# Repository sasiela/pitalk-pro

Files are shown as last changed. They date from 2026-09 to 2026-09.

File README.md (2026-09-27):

# PiTALK PRO

**[Download the complete latest STL set](releases/PITalk-Final-STL-V39-V42.zip)** · [STL files](stl/PITalk-Final-STL-V39-V42/)

**A Raspberry Pi radio terminal project with a custom, 3D-printable handheld enclosure.**

[Polski](README.pl.md) · [Printable parts](#printable-parts) · [Hardware](#hardware) · [Assembly](#assembly) · [Watch the demo](Video/PiTalk-Pro-z-lektorem.mp4)
[Changelog](CHANGELOG.md) · [Profiles / Profile](docs/build/PROFILES.md)

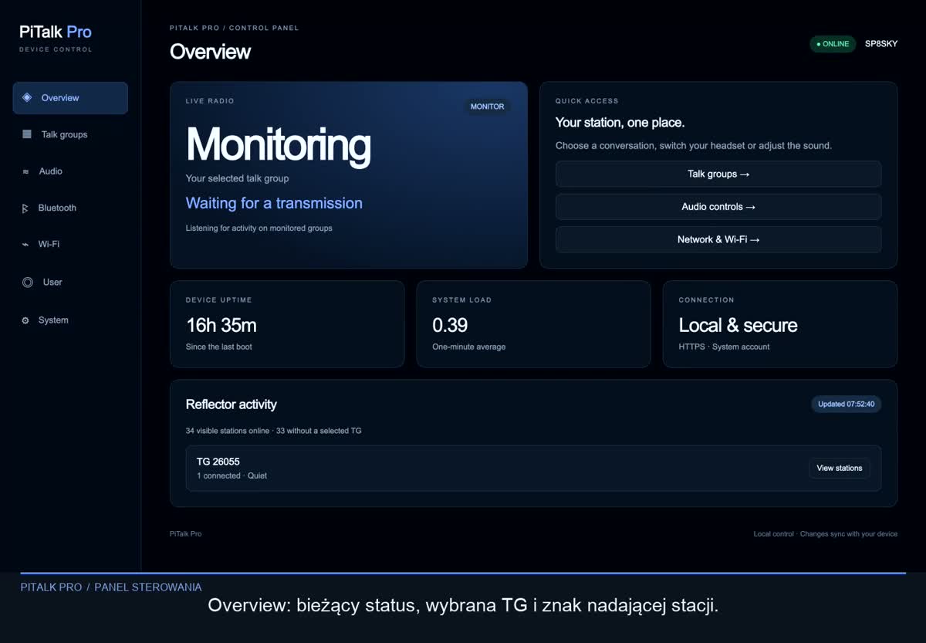
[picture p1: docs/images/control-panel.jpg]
PiTALK PRO control panel — open the demonstration video


*Control panel preview from the project demonstration. The video includes Polish narration.*

## Build your own PiTalk Pro

This repository is the shared home for the enclosure, software, configuration examples and build knowledge. Start with the [documentation hub (Polish)](docs/README.md), [build guide](docs/build/README.md), [parts list](docs/build/HARDWARE.md) and [project readiness](docs/project/READINESS.md).

**Current status: working prototype, reproduction in progress.** A complete clean-install procedure and physical alpha-image boot test are still pending. The repository does not yet provide a validated firmware download. See [contributing](CONTRIBUTING.md) to help complete the build documentation.

## About the project

PiTALK PRO brings a Raspberry Pi 3 Model B, an Adafruit PiTFT 2.2″ display and a Sabrent USB sound card into a custom enclosure inspired by classic handheld radios. Four physical buttons sit beside the display. The enclosure includes a separate front panel, ventilation, decorative knobs and a removable decorative antenna.

This repository contains **printable STL models, demonstration materials and a software source snapshot**. Start software development with [the project handoff](docs/handoff/START-HERE.md) and [software notes](software/README.md). The software snapshot and experimental image tooling are not yet a validated public firmware release.

The mechanical design was refined through repeated physical print-and-fit checks. The latest CAD pair is **V39 body + V42 front**, with **V11 button caps**; the previous V32/V38 set remains available. Fit still depends on the exact hardware and printer tolerances.

## Printable parts

Download the repository with **Code → Download ZIP**, or open an individual file below. Dimensions are in **millimetres**.

### Latest revision: EC11 body V39 + front V42

The latest CAD pair is **V39 body + V42 front**, extended by 8 mm at the top for one EC11 encoder and one decorative antenna. V42 has **two rows of three ventilation slots above the display**. Use these two revisions together.

| Part | Print | Editable CAD |
| --- | --- | --- |
| Body V39 | [STL](stl/ec11-v39-v42/01_Body_V39.stl) | [STEP](step/ec11-v39-v42/01_Body_V39.step) |
| Front V42 | [STL](stl/ec11-v39-v42/02_Front_Panel_V42.stl) | [STEP](step/ec11-v39-v42/02_Front_Panel_V42.step) |

Reuse four V11 caps and the decorative antenna/base from the list below. The old decorative knobs are not the encoder knob. The encoder knob and electrical integration are still pending. The 20 mm upper test print fitted; full assembly of this revision remains to be checked. See [revision dimensions and assembly differences](docs/build/MECHANICAL-EC11.md).

### Previous decorative-knob set: V32 + V38

| Part | STL file | Print quantity |
| --- | --- | ---: |
| Body with ventilation and reinforced nut mounts | [Body V32](stl/01_Body_V32.stl) | 1 |
| Flat front panel with display window and grille | [Front V38](stl/02_Flat_Front_Panel_V38.stl) | 1 |
| Rounded button cap | [Button cap V11](stl/03_Button_Cap_V11_Print_4.stl) | **4** |
| First decorative knob | [Control knob 1](stl/04_Control_Knob_1.stl) | 1 |
| Second decorative knob | [Control knob 2](stl/05_Control_Knob_2.stl) | 1 |
| Decorative antenna base | [Antenna base](stl/06_Antenna_Base.stl) | 1 |
| Decorative 70 mm antenna | [Antenna](stl/07_Decorative_Antenna_70mm.stl) | 1 |

**Seven STL files, ten printed parts.** The button-cap file contains a single cap.

### Current design details

- Flat front surface between the recessed grille rows, replacing the earlier raised curved ribs.
- Forty bottom ventilation slots in eight rows of five; each slot is 6.6 × 2.6 mm with R1 corners.
- Reinforced lower corner mounts joined to the enclosure walls.
- Side-entry pockets for M3 nuts measuring **5 mm across flats × 2 mm thick**. Pocket clearance is **5.5 × 2.6 mm**.
- Lower front fixings use **countersunk M3 × 12 mm screws**.
- V11 button caps are 3.5 mm tall overall, with an R0.6 top edge.

## Hardware

| Component | Design reference / notes |
| --- | --- |
| Raspberry Pi | **3 Model B**; compatibility with other boards has not been established |
| Display | **Adafruit PiTFT 2.2″ 240 × 320 HAT**, with four onboard buttons |
| USB audio | Sabrent adapter used in the prototype; measured housing approximately **34 × 23 × 10 mm** |
| Side push button | PBS-110-style momentary button matching the prototype; check dimensions before ordering |
| Lower front fasteners | **2 × countersunk M3 × 12 mm** and **2 × M3 nuts**, measured 5 mm across flats and 2 mm thick |
| Display/front fasteners | Four countersunk M3×12 screws and four spacers; spacer length still needs documenting |
| Power | External power supply appropriate for the Raspberry Pi; no internal battery compartment |

Measure replacement components before printing. A shared product name does not guarantee the same casing or shaft dimensions. Keep the existing display spacers and check the front screw length against the assembled stack.

The supplied knobs and antenna are **decorative**. The V39/V42 revision adds an EC11 mounting provision; its knob, wiring and software integration are not yet validated. External-radio PTT electronics are also outside this mechanical release.

## Printing

The project was developed using a **Creality K1**. PLA and Creality CR-PETG were used during development; this repository does not include a validated slicer profile or G-code.

- Inspect every model in your slicer and choose settings for your printer and material.
- Print the body with its exterior bottom on the build plate.
- The V38 front STL is positioned with its flat front toward the build plate. Check the first-layer preview and bed texture before printing.
- Review supports for overhangs, particularly the nut-pocket roofs, button-cap flanges and decorative parts.
- Print one button cap first and check movement in the front panel before printing the remaining three.
- A lower layer height can improve finish, but cannot compensate for poor orientation, support contact or inaccurate fit.

## Assembly

Follow the [full assembly guide](docs/build/ASSEMBLY.en.md), with the [illustrated Polish version](docs/build/ASSEMBLY.md). Assemble the front first:

1. Place the four button caps into the front slots.
2. Insert four M3×12 screws, fit the LCD and tighten gently.
3. Screw on the four spacers; set the completed front aside.
4. Solder two 10 cm wires to PTT and insulate the joints with heat-shrink tubing.
5. Mount PTT in the rear enclosure and secure its body with hot glue.
6. Bend physical Pi header pins 37 and 39 inward, solder the PTT wires and insulate the joints as described in the full guide.
7. Fit optional dongles into the lower USB sockets before placing the Pi in the case.
8. Insert the Raspberry Pi, then the two M3 nuts and the microSD card.
9. Install the USB sound adapter.
10. Fit the completed front and tighten the two lower M3×12 screws.

## Repository layout

```text
stl/                  Printable enclosure and accessory parts
Video/                Project demonstration with Polish narration
docs/images/          README preview image
README.md             English project page
README.pl.md          Polish project page
```

## Feedback

For fit problems, include the part/version, printer, material, layer height and a photo or measured discrepancy in a [GitHub issue](https://github.com/sasiela/pitalk-pro/issues).

## On-device updates / Aktualizacje z urządzenia

[System Update: instrukcja i zakres aktualizacji](docs/build/UPDATES.md). Pierwsza wersja obejmuje ekran i enkoder; nie aktualizuje całego systemu ani panelu WWW.

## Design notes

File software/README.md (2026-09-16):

# PiTalk Pro software snapshot

Start with [the project handoff](../docs/handoff/START-HERE.md) and [AGENTS.md](../AGENTS.md).

`rootfs/` mirrors installation paths for the current Python application, web assets, systemd units and supporting scripts. It is an exported source snapshot, not a complete Raspberry Pi filesystem or automatic installer. Owner identifiers were scrubbed; the web LAN filter contains example addresses and requires adjustment before deployment. `manifest.json` records source/export hashes and original permissions.

`examples/` contains credential-free configuration examples. Never overwrite an active configuration with these templates. `image-tools/` contains experimental alpha image tooling and its limitations. Read its README before use.

Run `python3 software/check-source.py` from the repository root for static checks. These do not test actual hardware. The repository does not establish a new license for bundled upstream service files; preserve their existing notices and review licensing before distribution.

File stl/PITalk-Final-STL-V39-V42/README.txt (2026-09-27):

PiTALK PRO — latest STL set — 2026-09-27
Units: millimetres.

01_Body_V39.stl — print 1
02_Front_Panel_V42.stl — print 1 (two upper ventilation rows)
03_Button_Cap_V11_Print_4.stl — print 4 (original 3.5 mm height)
04_Antenna_Base.stl — print 1
05_Decorative_Antenna_70mm.stl — print 1

5 STL files, 8 printed pieces.
Body V39 and front V42 are the matching extended EC11 revision.
Old decorative knobs are not included: this revision uses one real EC11
encoder. A matching encoder knob has not yet been designed.
The upper test print fitted; full assembly of V39/V42 remains to be verified.
Previous versions have been preserved separately.

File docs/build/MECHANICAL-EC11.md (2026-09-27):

# EC11 mechanical revision — V39 body / V42 front

Updated: 2026-09-26. Units: mm. This is the latest CAD revision, not a fully validated assembled release.

## Files and compatible parts

- [Body V39 STL](../../stl/ec11-v39-v42/01_Body_V39.stl) / [STEP](../../step/ec11-v39-v42/01_Body_V39.step).
- [Front V42 STL](../../stl/ec11-v39-v42/02_Front_Panel_V42.stl) / [STEP](../../step/ec11-v39-v42/02_Front_Panel_V42.step).
- Reuse [V11 caps](../../stl/03_Button_Cap_V11_Print_4.stl), four prints, and the existing [antenna base](../../stl/06_Antenna_Base.stl) and [70 mm decorative antenna](../../stl/07_Decorative_Antenna_70mm.stl).
- Previous decorative knobs are legacy parts. A matching encoder knob is not included.

## Geometry

The upper body and front extend by 8 mm. PCB supports, display position and existing screw axes stay in place. The upper walls are continuous; the antenna-side bulge reaches the upper edge. The old microSD opening is closed. There is one EC11 position and one antenna position; the middle decorative-knob position is removed.

Encoder reference supplied by the builder: body 12 × 12 × 5, depth including terminals 10, shaft plus threaded section 20. The mounting hole is Ø7.2; verify the actual threaded bush, washer and nut before assembly. The nominal 10 mm envelope reaches 1.7 mm into the PCB footprint, so clearance to real components and wiring must be checked in the complete assembly. Shaft flat, usable shaft length and push travel still need confirmation for the knob.

| Feature | Dimensions |
| --- | --- |
| Rear holes through four existing PCB supports | Ø3.4 |
| Rear countersinks | Ø6.4 at surface, depth 2.2 |
| Rear screw-axis rectangle | 58 × 49 |
| Bottom vents | 40 slots, 8 rows × 5; 6.6 × 2.6, R1 |
| Bottom vent placement | Centered between the four rear screw axes |
| Above-screen vents | 2 rows × 3; 6.6 × 2.6, R1 |
| Above-screen row pitch / material gap | 6 / 3.4 |

## Assembly differences / różnice montażowe

The [illustrated assembly guide](ASSEMBLY.en.md) describes the earlier prototype. For this revision:

1. Trial-fit the encoder and its retaining nut before installing the electronics. Check terminal insulation and clearance to both Pi and display HAT.
2. Insert the microSD before closing the enclosure; there is no external card slot.
3. Rear M3 screws must mate with suitable threaded spacers. Select screw length from the actual assembled stack; the existing M3×12 front screws do not establish the required rear length.
4. Reuse the established front fasteners and V11 caps. Check free button travel after closing.
5. Encoder wiring and software support are not provided by this mechanical change.

Po polsku: montuj V39 z V42. Przymierz enkoder przed elektroniką, sprawdź izolację i kolizje pinów, a kartę microSD włóż przed zamknięciem. Długość tylnych śrub M3 dobierz do rzeczywistych gwintowanych dystansów. Stare pokrętła są ozdobne; nowa gałka i podłączenie EC11 wymagają dopracowania.

## Verification

- Builder confirmed that the 20 mm upper-body test print fitted.
- CAD checks: valid single solids, STEP reimport successful, 40 body vents and six upper-front vents open, no body/front intersection in the checked assembly.
- Full V39/V42 physical assembly, rear fasteners, encoder clearance with soldered wires, and encoder operation remain unverified.
- Check orientation and supports in the slicer; these files do not include a validated print profile.

## Zestaw do pobrania — 2026-09-27

[Kompletny ZIP STL V39/V42](../../releases/PITalk-Final-STL-V39-V42.zip): 5 modeli, 8 drukowanych części. Sprawdzono zgodność kopii i integralność archiwum. Zakres potwierdzenia montażu pozostaje bez zmian; gałka EC11 nie jest jeszcze gotowa.

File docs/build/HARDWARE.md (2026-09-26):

# Sprzęt i połączenia

## Zestaw odniesienia

Lista opisuje użyty prototyp, a nie gwarantowane zamienniki. Wersja maszynowa: [parts.csv](parts.csv).

| Element | Ilość | Znane dane / do uzupełnienia |
| --- | ---: | --- |
| Raspberry Pi 3 Model B Rev 1.2 | 1 | Model potwierdzony odczytem systemu |
| Adafruit PiTFT 2.2″ 240×320 HAT | 1 | Cztery przyciski; overlay `pitft22` |
| Karta dźwiękowa USB Sabrent | 1 | Obudowa prototypu około 34×23×10 mm; dokładny numer produktu i identyfikator USB do zapisania |
| Boczny przycisk chwilowy | 1 | Typ PBS-110 zgodny wymiarami z prototypem; przed zakupem sprawdzić konkretny wariant |
| microSD | 1 | Obraz alpha wymaga minimum 8 GB; karta testowa osobna od działającej instalacji |
| Zewnętrzne zasilanie i kabel | 1 zestaw | Dokładny model zasilacza i sprawdzenie pracy pod obciążeniem do udokumentowania |
| Mikrofon i odsłuch USB lub zestaw Bluetooth | 1 tor | Brak kompletnej listy sprawdzonych modeli i okablowania audio |
| Śruby stożkowe M3×12 | 2 | Dolne mocowanie frontu |
| Nakrętki M3 | 2 | W prototypie 5 mm między płaskimi bokami, grubość 2 mm |
| Śruby M3×12 do LCD / dystanse | 4 śruby + 4 dystanse | Śruby potwierdzone przez autora; długość dystansów do zwymiarowania |
| Przewody PTT i izolacja | 2 × około 10 cm | Koszulki termokurczliwe na każdym lucie; klej na gorąco do zamocowania przycisku |
| Części drukowane — poprzedni zestaw | 10 | Korpus V32, front V38, 4 nakładki V11, 2 pokrętła, podstawa i antena |
| Najnowsza mechanika EC11 | Zobacz opis | [Korpus V39 + front V42](MECHANICAL-EC11.md), 4 nakładki V11, podstawa i antena; gałka enkodera do opracowania |

## Połączenia

Poniższe numery to **BCM, nie kolejne numery fizycznych pinów złącza**. Tabela opisuje konfigurację oprogramowania. Nie zastępuje sprawdzonego schematu montażowego.

| BCM | Rola |
| --- | --- |
| 17 | Przycisk BACK na PiTFT |
| 22 | Przycisk UP na PiTFT |
| 23 | Przycisk DOWN na PiTFT |
| 27 | Przycisk ENTER na PiTFT |
| 26 | Wejście PTT, pull-up, aktywne LOW; programowy debounce 30 ms |
| 24 | Programowy sygnał squelch: HIGH oznacza idle, LOW aktywuje wejście SvxLink |

Przycisk PTT łączy **fizyczny pin 37 (GPIO26)** z **fizycznym pinem 39 (GND)** po wciśnięciu. Autor podał tę kolejność montażu, a [zdjęcie połączeń](../../photos/IMG_3615.jpeg) pokazuje luty zabezpieczone koszulkami. Pełny opis i źródło numeracji: [instrukcja montażu](ASSEMBLY.md#numeracja-i-kontrola-ptt). Powyższa tabela nadal używa numeracji BCM. Nie podłączaj wyjścia zewnętrznego radia do wejścia przycisku.

GPIO24 jest sterowane przez system jako `gpio536` w prototypie. Ta liczba zależy od mapowania GPIO w jądrze. Nie jest numerem fizycznego pinu. Nie przenoś jej bez sprawdzenia na inny model/system.

## Mechanika i dokumentacja zdjęciowa

Obowiązują [wersje STL i instrukcja montażu](../../README.pl.md). Najpierw wydrukuj jedną nakładkę i wykonaj przymiarkę. Pokrętła i antena są ozdobne; nie ma zintegrowanego akumulatora ani potwierdzonej obsługi enkoderów.

[Instrukcja montażu ze zdjęciami](ASSEMBLY.md) prowadzi od frontu, przez PTT, do zamknięcia obudowy. [Indeks zdjęć](../../photos/README.md) opisuje wszystkie 24 pliki. Ostatnie etapy zamknięcia obudowy są opisane według autora, ale nie mają jeszcze osobnych zdjęć. Wymiary dystansów i kompletny rysunek montażowy pozostają do uzupełnienia.

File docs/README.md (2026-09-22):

# PiTalk Pro — dokumentacja projektu

Celem repozytorium jest umożliwienie innej osobie zbudowania, skonfigurowania i rozwijania własnego PiTalk Pro. Wspólnie przechowujemy obudowę, kod, konfiguracje przykładowe, instrukcje i wyniki testów. Wiedza potrzebna do budowy nie powinna wymagać dostępu do prywatnej rozmowy ani komputera autora.

**Stan: działający prototyp i dokumentowana wersja rozwojowa.** Instrukcja odtworzenia na czystej karcie nie została jeszcze potwierdzona. Nie ma opublikowanego, przetestowanego wydania obrazu ani kompletnego instalatora. Braki są widoczne w [statusie odtwarzalności](project/READINESS.md).

## Chcę zbudować urządzenie

1. [Przewodnik budowy](build/README.md) — kolejność prac i punkty kontrolne.
2. [Sprzęt i połączenia](build/HARDWARE.md) — części, GPIO i brakujące dane.
3. [Montaż krok po kroku ze zdjęciami](build/ASSEMBLY.md) oraz [pliki STL](../stl/).
4. [Instalacja i pierwsza konfiguracja](build/SOFTWARE.md) — dostępne ścieżki i ich ograniczenia.
5. [Test własnego egzemplarza](testing/ACCEPTANCE.md) — co sprawdzić przed uznaniem budowy za zakończoną.

## Chcę używać lub rozwijać projekt

- [Architektura](handoff/ARCHITECTURE.md) i [obsługa/diagnostyka](handoff/OPERATIONS.md).
- [Znane problemy](handoff/KNOWN-ISSUES.md) oraz [historia decyzji interfejsu](handoff/HISTORY-AND-UX.md).
- [Kod](../software/README.md), [zasady współpracy](../CONTRIBUTING.md), [instrukcje dla asystentów](../AGENTS.md).
- [Obraz i backupy](handoff/IMAGE-AND-BACKUPS.md), [status przygotowania wydania](project/READINESS.md).

Materiały w `docs/handoff/` zachowują kontekst rozwoju. Niniejszy katalog jest punktem wejścia dla wszystkich budujących, niezależnie od używanego edytora lub asystenta.

## Profile połączenia

[Konfiguracja i obsługa profili SQLink / Fala](build/PROFILES.md) — wspólne dla ekranu i panelu WWW.

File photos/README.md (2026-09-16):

# Zdjęcia montażu

[Instrukcja krok po kroku](../docs/build/ASSEMBLY.md). Poniżej wszystkie 24 zdjęcia w kolejności nazw plików. Kolejność montażu określa instrukcja autora; IMG_3612 wraca do detalu wcześniej przygotowanego frontu. Oryginałów nie zmieniono.

| Zdjęcie | Co pokazuje |
| --- | --- |
| [IMG_3595](IMG_3595.jpeg) | Front od środka: nakładki w slotach i cztery śruby. |
| [IMG_3596](IMG_3596.jpeg) | Cztery dystanse przed montażem. |
| [IMG_3597](IMG_3597.jpeg) | Płytka PiTFT nałożona na śruby frontu. |
| [IMG_3598](IMG_3598.jpeg) | Widok frontu z zamontowanym LCD. |
| [IMG_3599](IMG_3599.jpeg) | Front z LCD — drugi widok. |
| [IMG_3600](IMG_3600.jpeg) | Front z LCD — widok pod kątem. |
| [IMG_3601](IMG_3601.jpeg) | Cztery dystanse przykręcone z tyłu LCD. |
| [IMG_3602](IMG_3602.jpeg) | Pusta tylna część obudowy. |
| [IMG_3603](IMG_3603.jpeg) | Przycisk PTT przed przygotowaniem przewodów. |
| [IMG_3604](IMG_3604.jpeg) | Przewody przylutowane do PTT, luty w koszulkach. |
| [IMG_3605](IMG_3605.jpeg) | Wnętrze obudowy i gniazdo przycisku. |
| [IMG_3606](IMG_3606.jpeg) | Wnętrze obudowy — inne ujęcie. |
| [IMG_3607](IMG_3607.jpeg) | Podpory płytki i przestrzeń montażowa. |
| [IMG_3608](IMG_3608.jpeg) | PTT osadzony w obudowie, przewody prowadzą do wnętrza. |
| [IMG_3610](IMG_3610.jpeg) | Ułożenie przewodów od zamontowanego PTT. |
| [IMG_3611](IMG_3611.jpeg) | Korpus PTT zabezpieczony klejem na gorąco. |
| [IMG_3612](IMG_3612.jpeg) | Zbliżenie tylnej strony LCD z dystansami. |
| [IMG_3613](IMG_3613.jpeg) | Raspberry Pi przed przylutowaniem przewodów; końcówka złącza przygotowana. |
| [IMG_3614](IMG_3614.jpeg) | Obudowa połączona przewodami PTT z płytką leżącą obok. |
| [IMG_3615](IMG_3615.jpeg) | Zbliżenie połączeń PTT i koszulek przy pinach 37 i 39. |
| [IMG_3616](IMG_3616.jpeg) | Raspberry Pi umieszczone w obudowie. |
| [IMG_3617](IMG_3617.jpeg) | Raspberry Pi w obudowie — ułożenie przewodów. |
| [IMG_3618](IMG_3618.jpeg) | Widok otworu dostępu do gniazda microSD. |
| [IMG_3619](IMG_3619.jpeg) | Karta dźwiękowa USB Sabrent przed instalacją. |

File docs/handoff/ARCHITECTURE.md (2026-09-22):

# Architektura i sprzęt

## Platforma odniesienia

Raspberry Pi 3 Model B Rev 1.2, Debian GNU/Linux 13 (trixie), aarch64. W czasie diagnozy system podawał Debian 13.6 i kernel 6.18.39+rpt-rpi-v8. Wyświetlacz Adafruit PiTFT 2.2 cala, 240×320, nakładka `pitft22`. Ekran jest rysowany przez Pillow i zapisywany do `/dev/fb0` jako RGB565. Czcionki DejaVu są zależnością systemową. To nie aplikacja desktopowa ani strona na samym ekranie PiTFT.

| GPIO BCM | Funkcja |
| --- | --- |
| 17 | BACK |
| 22 | UP |
| 23 | DOWN |
| 27 | ENTER |
| 26 | Przytrzymywany przycisk PTT, wejście z pull-up, aktywne zero |
| 24 | Programowy sygnał otwarcia squelcha; w tym jądrze sysfs `gpio536` |

Nie traktuj liczby 536 jako uniwersalnego numeru GPIO. Wynika z mapowania konkretnego systemu. Przycisk PTT był testowany z eliminacją drgań 30 ms; bez niej rejestrował serię krótkich zboczy.

## Warstwy

- `/usr/local/bin/sqlink-screen.py`: główny ekran i menu, przyciski, renderowanie, TG i wskaźniki.
- `/usr/lib/sqlink/`: kontroler, API SQLink, stan reflektora, GPIO, audio, motywy i edytory poszczególnych menu.
- `/usr/local/bin/sqlink-ptt-button.py`: oddzielny proces przycisku, debounce 30 ms, uzbrojenie dopiero po puszczeniu przycisku, watchdog i zwolnienie PTT przy wyjściu.
- `/usr/local/sbin/sqlink-gpio-setup.sh`: eksport GPIO24/sysfs, atomowe ustawienie stanu idle HIGH, prawa do sterowania dla aplikacji.
- `svxlink.service`: silnik głosu i połączenie z reflektorem. Konfiguracja zawiera SimplexLogic i ReflectorLogic połączone przez ReflectorLink.
- Uprzywilejowane helpery Wi-Fi oraz Bluetooth: wykonują ograniczone operacje systemowe za pośrednictwem lokalnych socketów Unix.
- `/opt/sqlink-web/server.py` i `static/`: lokalny panel WWW. Korzysta z tych samych modułów i helperów co ekran.

## PTT i audio

GPIO26 → proces PTT → `sqlink.gpio` → GPIO24 w stanie LOW → `Rx1` z `SQL_DET=GPIO` i `GPIO_SQL_PIN=!gpio536` → audio mikrofonu do SvxLink/reflektora. W konfiguracji prototypu `Tx1` ma `PTT_TYPE=NONE`. Jest to sterowanie lokalnym wejściem głosowym do sieci; nie oznacza gotowego interfejsu PTT zewnętrznego radiotelefonu.

SvxLink używa `AUDIO_DEV=alsa:pipewire`. PipeWire, warstwa zgodna z PulseAudio i WirePlumber pracują w sesji konta `sqlink`. UID 1002 jest wpisany w kilka usług i ścieżek `/run/user/1002`. Wybór USB/Bluetooth oraz głośność opierają się na `pactl` i helperze Bluetooth. Profile Bluetooth mają znaczenie dla wejścia mikrofonowego i jakości dźwięku; nie zakładaj, że każdy profil zapewnia równocześnie to samo wejście i wyjście.

## Stan TG i nadawcy

`/usr/share/svxlink/events.d/local/RadioStatus.tcl` opakowuje zdarzenia ReflectorLogic (`tg_selected`, `talker_start`, `talker_stop`). Zapisuje atomowo `/dev/shm/sqlink-radio-state`: PID, TG, flaga odbioru i callsign. Czytelnicy porównują PID z `/run/svxlink.pid`, aby odrzucić stan sprzed restartu.

- MONITOR: brak aktywnego RX/TX przy gotowości do nasłuchu.
- RX: aktualnie odbierana transmisja; wyświetlany jest callsign i pasek audio.
- TX: aktywny lokalny PTT. Nie jest to dowód, że mikrofon faktycznie dostarcza sygnał lub że transmisja dotarła do serwera.
- ONLINE/OFFLINE: rzeczywisty lokalny stan połączenia SvxLink. API statusu serwera daje informacje dodatkowe.

`radio_status.py` pobiera próbki przez `parec` w osobnym wątku; szybsze rysowanie miernika nie powinno wymuszać kosztownych zapytań sieciowych przy każdej klatce.

## Panel WWW

HTTPS na porcie 8443, Python HTTP server i statyczny HTML/CSS/JS. Ekrany: Overview, Talk groups, Audio, Bluetooth, Wi-Fi, User, System. Logowanie jako systemowy użytkownik `sqlink` przez PAM (`/etc/pam.d/sqlink-web`, helper `sqlink_web_auth.py`). To nie hasło do reflektora. Sesje są trzymane w pamięci, dlatego restart panelu może wymagać ponownego logowania. Operacje używają tokenu CSRF; panel ma filtr klienta LAN i nagłówka Host.

Talk groups pokazuje aktywność, wybraną TG i listy stacji. „Connected” oznacza aktualnie wybraną TG według danych serwera. „Monitoring” oznacza skonfigurowaną listę monitorowania, nie gwarancję aktywnego odbioru w tej chwili. Kliknięcie callsign otwiera szczegóły stacji z dostępnych danych API, nie zdalną konfigurację administracyjną tej stacji.

Odsłuch: `/api/listen` → `listen_audio.py` → monitor bieżącego wyjścia PulseAudio (`<sink>.monitor`) → PCM s16le/16 kHz/mono → AudioWorklet przeglądarki. Maksymalnie cztery strumienie. Poza RX wysyłana jest cisza. Strumień nie zapisuje nagrania i nie zabiera dźwięku urządzeniu. Głośność przeglądarki jest osobna. Zmiana domyślnego wyjścia jest wykrywana podczas odsłuchu. Zamknięcie Overview, Stop lub wylogowanie zatrzymuje odsłuch.

Pułapka: `ProtectHome=yes` w usłudze ukrywa `/run/user`. Działający prototyp używa bind mount socketu PulseAudio do `/run/sqlink-web-audio` i zmiennej `PULSE_SERVER`. Obraz alpha ma inny wariant: bind całego runtime użytkownika z zależnością od `user@1002.service`. Nie mieszaj tych wariantów bez sprawdzenia startu usług.

## Testy audio WWW

`audio_test.py` obsługuje jedno ograniczone czasowo zadanie należące do sesji. Paplay odtwarza wygenerowany ton, parec odczytuje domyślny mikrofon i oblicza poziom bez zapisu nagrania. GET/POST `/api/audio-test`; frontend odpytuje stan co 250 ms. Test nie steruje GPIO; odczytuje stan radia i przerywa przy RX/PTT. [Instrukcja i sprawdzenia](../build/AUDIO-TESTS.md).

## Profile reflektorów (22 września 2026)

`sqlink_profiles.py` zastępuje bezpośrednią edycję konta w User. Root przechowuje bazę prywatną i publikuje metadane aktywnego profilu do `profile_state.py`. UI PiTFT i `/api/profiles` korzystają ze wspólnego helpera. API nazw i stacji jest ograniczone do dostawcy danego profilu; None nie odpytuje SQLink. Usługa `sqlink-profiles.service` przygotowuje konfigurację domyślnego profilu na rozruch. [Pełny opis](../build/PROFILES.md).

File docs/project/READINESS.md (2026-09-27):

# Kompletność i droga do wydania

Aktualizacja: 16 września 2026. Cel: repozytorium ma wystarczać do zbudowania własnego urządzenia, bez dostępu do prywatnych danych autora.

| Obszar | Stan | Następny konkretny rezultat |
| --- | --- | --- |
| Modele i mechanika | STL, kolejność autora i instrukcja zdjęciowa dostępne | Zdjęcia końcowego zamknięcia i wymiary dystansów |
| Lista części | Referencje dostępne, niektóre identyfikatory niepełne | Numery produktów/USB, zasilanie i komplet audio |
| Schemat | BCM oraz PTT na fizycznych 37/39 opisane i pokazane | Kompletny rysunek montażowy i tor audio |
| Kod | Eksport działającego prototypu i manifest | Konfiguracja niezależna od stałego IP, UID i gpio536 |
| Instalacja od zera | Niekompletna | Powtarzalny instalator z wersją OS i zależności |
| Obraz alpha | Plik lokalny, kontrola struktury i sum wykonana | Rozruch i pełny test na osobnej karcie |
| Pierwsza konfiguracja | Skrypt i symulacja dostępne | Test poprawnych i błędnych danych na sprzęcie |
| Instrukcja użytkownika | Funkcje opisane w dokumentacji rozwoju | Zrzuty i prosta instrukcja każdej funkcji dla nowej osoby |
| Aktualizacja / recovery | Opisane zasady, prywatne backupy istnieją | Sprawdzona procedura aktualizacji i odtworzenia |
| Testy | Statyczne i symulacja; obserwacje prototypu | Wypełniony protokół dla czystej instalacji i drugiego egzemplarza |
| Licencje i materiały źródłowe | Nie ustalono kompletnego zestawu | Decyzja właściciela dla kodu/STL/docs i zachowane informacje o zależnościach |
| Publikowane wydanie | Brak potwierdzonego obrazu wydania | Paczka obrazu + SHA-256 + źródła + instrukcja + raport zgodnych wersji |

## Co znaczy „kompletne”

Nowa osoba potrafi dobrać części, wykonać połączenia, złożyć obudowę, zainstalować system, wprowadzić własne dane, sprawdzić działanie i odtworzyć backup. Każdy potrzebny krok ma opis lub zweryfikowany automat. Wynik został odtworzony na drugim egzemplarzu. Znane ograniczenia są jawne.

## Kolejność uzupełnienia

1. Uzupełnić schemat i konkretne identyfikatory części.
2. Przeprowadzić test alpha na zapasowej karcie i zapisać wyniki.
3. Usunąć zależności od sieci i konta prototypu, przygotować powtarzalną instalację.
4. Poprosić drugą osobę o budowę według dokumentacji i poprawić niejasności.
5. Ustalić licencje, przygotować wersjonowane wydanie i dopiero wtedy udostępnić obraz.

## Zasada utrzymania

Przy zmianie sprzętu aktualizujemy listę części i schemat. Przy zmianie funkcji — instrukcję oraz test. Przy zmianie instalacji — receptę budowy i odtworzenia. Przy wydaniu — raport zgodnej konfiguracji i sumy artefaktów. Prywatne dane użytkowników nie są częścią projektu.

## Aktualizacja — testy audio WWW, 17 września 2026

Dodano test wyjścia oraz miernik mikrofonu. Testy logiki/API i symulacja UI przeszły; na prototypie zweryfikowano procesy USB. Słyszalność, reakcja na mowę i zestaw Bluetooth wymagają potwierdzenia użytkownika. [Zakres i instrukcja](../build/AUDIO-TESTS.md). Obraz alpha-1 bez tej zmiany.

## Aktualizacja — profile, 22 września 2026

Wdrożono wspólne profile reflektorów w menu i WWW, aktywację z przywracaniem konfiguracji oraz wybór domyślnego profilu na rozruch. Import i zapis sprawdzono na prototypie; w końcowej kontroli Fala była już aktywna i połączona. Audio/TG Fali, powrót do SQLink i restart z drugim profilem pozostają do testu. [Instrukcja, wyniki i ograniczenia](../build/PROFILES.md). Obraz alpha-1 bez tej aktualizacji.

## Mechanika — 2026-09-26

Dodano [korpus V39 i front V42 pod EC11](../build/MECHANICAL-EC11.md), w STL i STEP. Potwierdzona przymiarka próbnego górnego odcinka 20 mm; sprawdzona geometria CAD i brak kolizji korpus–front. Do potwierdzenia pozostaje pełny montaż, dobór tylnych śrub, luz enkodera z przewodami oraz jego gałka i obsługa elektryczna/programowa. Poprzedni zestaw V32/V38 zachowano.

## Zestaw do pobrania — 2026-09-27

[Kompletny ZIP STL V39/V42](../../releases/PITalk-Final-STL-V39-V42.zip): 5 modeli, 8 drukowanych części. Sprawdzono zgodność kopii i integralność archiwum. Zakres potwierdzenia montażu pozostaje bez zmian; gałka EC11 nie jest jeszcze gotowa.

## Aktualizator — 2026-09-27

[System Update](../build/UPDATES.md): implementacja i testy lokalne instalacji/rollbacku gotowe. Pełny fizyczny cykl aktualizacji pozostaje do sprawdzenia po rozwiązaniu undervoltage. Nie oznacza gotowego obrazu firmware.

### Wdrożenie prototypu — 2026-09-27

Zainstalowano i włączono usługę aktualizatora za zgodą właściciela. Ekran oraz helper aktywne, bez automatycznych restartów; świeży heartbeat po zapisie obrazu. Sprawdzenie GitHub zwróciło `Up to date`, zainstalowana i dostępna wersja `pitalk-v0.1.0`. Urządzenie nadal zgłasza bieżące undervoltage (`0x50005`); pełnej instalacji kolejnego wydania ani fizycznego rollbacku nie testowano.

### Poprawka interfejsu 0.1.2 — 2026-09-27

Wersja `pitalk-v0.1.2` poprawia układ System Update: nagłówek obok ikony powrotu, wspólne zaznaczenie, osobne miejsce na potwierdzenie i maksymalnie trzy linie komunikatu. Wybierz Check for updates, następnie Install update i Install now. Po instalacji sprawdź Current: pitalk-v0.1.2 oraz brak nakładania napisów. Rendery sprawdzono lokalnie; instalacja i wygląd na fizycznym LCD wymagają potwierdzenia właściciela.

### Panel WWW — przygotowany 2026-09-27

System zawiera sekcję System Update: wersje, ręczne sprawdzenie, potwierdzenie instalacji i status odświeżany w tle. API wymaga sesji, operacje POST także CSRF; używa istniejącego ograniczonego helpera. Brak helpera jest widoczny jako niedostępność bez blokowania pozostałego panelu. Sprawdzanie przy starcie urządzenia i monit LCD nie są jeszcze zaimplementowane.

Właściciel potwierdził działanie aktualizacji 0.1.2 z terminala. GitHub + menu urządzenia to uzgodniony kanał aktualizacji. Obecna lista czterech plików nie obejmuje WWW: ta zmiana panelu nie jest jeszcze wdrożona ani oferowana przez stable.json. Rozszerzenie instalatora wymaga osobnej migracji; nie wolno nadpisać prywatnego filtra LAN przykładowym server.py z repozytorium.

### Rozszerzony instalator i wydanie 0.1.3

Jednorazowa migracja prototypu 2026-09-27 zachowała filtr LAN w `/etc/sqlink-web/access.json` i rozszerzyła helper o siedem plików WWW (łącznie 11 plików wydania). Usługa działa; kopia poprzedniego helpera i unitu jest w `/var/backups/pitalk-web-bootstrap-20260927-194540`. Aplikacja pozostała 0.1.2 do instalacji z menu.

0.1.3 dostarcza panel WWW z aktualizacjami. Instalacja restartuje ekran i WWW (sesja przeglądarki oraz odsłuch zostaną przerwane); kontroluje heartbeat ekranu, aktywność WWW i odpowiedź HTTPS przez 20 sekund. W razie błędu przywraca wszystkie pliki transakcji. Stare wydania czteroplikowe pozostają obsługiwane. Stary helper nie zainstaluje wydania 11-plikowego: wymaga najpierw migracji administracyjnej.

Na nowym urządzeniu utwórz `/etc/sqlink-web/access.json` zgodnie z `software/examples/sqlink-web-access.json.example`, ustawiając rzeczywistą podsieć i dozwolone nazwy. Brak konfiguracji blokuje dostęp, nie otwiera panelu. Plik jest poza wydaniem i nie jest nadpisywany przez update. Fizyczny test instalacji 0.1.3 oczekuje na operatora. Automatyczny monit po starcie nadal nie jest częścią tej wersji.

### System Info — 0.1.4

Dodano zakładkę WWW System Info: wersja zainstalowana i ostatnio sprawdzona, model, hostname, OS, kernel, architektura, uptime, temperatura CPU oraz bieżące i historyczne flagi napięcia/throttlingu. Dane są migawką odświeżaną przy otwarciu lub przyciskiem Refresh. Brak źródła oznacza Unavailable. API wymaga logowania. Testy obejmują 0x0, 0x50000, 0x50005 i niedostępne czujniki; wygląd i odczyty na fizycznym urządzeniu wymagają potwierdzenia po instalacji. Wydanie korzysta z rozszerzonego aktualizatora WWW.

### System Info na PiTFT — 0.1.5

Menu urządzenia ma trzy strony: Software, Hardware, Power status. UP/DOWN lub obrót enkodera zmienia stronę, ENTER odświeża, BACK wraca do menu. Odczyty odbywają się w tle, także co 10 sekund podczas otwartego okna. Niedostępne wartości oznaczono Unavailable. Sprawdzono rendery 240×320 i składnię; fizyczny wygląd pozostaje do potwierdzenia po instalacji. Nie wymaga kolejnej migracji helpera.

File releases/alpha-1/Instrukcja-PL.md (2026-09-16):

# PiTalk Pro — obraz testowy alpha-1

Obraz zawiera aktualny system PiTalk Pro: ekran PiTFT, menu urządzenia, PTT, obsługę Wi-Fi i Bluetooth, SvxLink oraz panel WWW z odsłuchem audio.

## Zakres testu

Przygotowano plik obrazu. Nie zapisano żadnej karty i nie wykonano fizycznego testu uruchomienia. Wersja jest przeznaczona do prywatnych testów, jeszcze nie do publicznej dystrybucji.

Sprzęt odniesienia: Raspberry Pi 3 Model B Rev 1.2, wyświetlacz PiTFT 2,2 cala 240×320 z nakładką `pitft22`, przyciski GPIO17/22/23/27, PTT GPIO26 i karta dźwiękowa USB. Inne modele Raspberry Pi i ekrany nie są potwierdzone.

## Wgranie na zapasową kartę

1. Przygotuj osobną kartę microSD minimum 8 GB. Zapis obrazu usunie jej dotychczasową zawartość.
2. W Raspberry Pi Imager wybierz **Use Custom / Użyj własnego obrazu** i plik `PiTalk-Pro-alpha-1.img.gz`. Nie trzeba go rozpakowywać.
3. Wybierz kartę. W tej wersji **pomiń personalizację systemu w Imagerze**; używamy własnego pliku konfiguracji.
4. Po zapisie i weryfikacji ponownie włóż kartę do Maca. Otwórz widoczną partycję `bootfs`.
5. Edytuj `pitalk-setup.json` jako zwykły tekst, zachowując poprawną składnię JSON. Ustaw własne `system_password` — 12–128 znaków, bez dwukropka. Nie ma wspólnego fabrycznego hasła.
6. Jeśli używasz Wi-Fi, uzupełnij `wifi_ssid`, `wifi_password` i kod kraju `wifi_country`. Przy pierwszym teście można użyć Ethernetu i pozostawić pola sieci puste. Ta wersja obsługuje w pliku konfiguracji sieci WPA Personal.
7. Dane reflektora są opcjonalne. Podaj własne `callsign` i `reflector_password` albo zostaw oba puste i skonfiguruj je później w **Menu → User**. Hasło reflektora i hasło systemowe to dwie różne rzeczy.
8. Bezpiecznie wysuń kartę i uruchom Raspberry Pi. Pierwsza konfiguracja może potrwać kilka minut.

## Pierwsze uruchomienie

System generuje nowe klucze SSH i własny certyfikat HTTPS, ustawia hasło konta `sqlink`, konfiguruje sieć i podejmuje próbę powiększenia partycji root na całą kartę. Domyślna nazwa w pliku konfiguracji to `pitalk-pro`. Panel będzie dostępny pod `https://pitalk-pro.local:8443`, jeśli sieć obsługuje nazwy mDNS `.local`. Możesz zmienić nazwę; puste pole `hostname` tworzy unikalną nazwę `pitalk-xxxxxx`.

Po poprawnej konfiguracji plik `pitalk-setup.json` jest nadpisywany i usuwany. Wynik znajduje się w `PITALK-STATUS.txt` na partycji bootfs. Jeżeli konfiguracja się nie uda, popraw JSON i uruchom urządzenie ponownie.

Panel: `https://ADRES-IP:8443` albo `https://NAZWA.local:8443`.

Login WWW i SSH: **sqlink**. Hasło: własne `system_password`. Polecenia administracyjne `sudo` wymagają tego hasła; logowanie SSH bezpośrednio jako root jest wyłączone.

Adres IP sprawdzisz w **Menu → WiFi** albo w routerze. Certyfikat jest lokalny i samopodpisany, więc przeglądarka pokaże ostrzeżenie — przed zaakceptowaniem sprawdź adres urządzenia.

Jeśli nie wpisano danych reflektora, radio pozostaje niepołączone. Wprowadź własne konto w **Menu → User → Save & reconnect**.

## Kontrola obrazu

- Sprawdź sumę pliku poleceniem `shasum -a 256 -c SHA256SUMS` w katalogu obrazu.
- Raporty dołączone do obrazu opisują kontrolę partycji, systemów plików i skan danych właściciela.
- Obraz zbudowano na nowym systemie plików z oczyszczonych plików; nie jest to surowa kopia karty zawierająca jej stare wolne bloki.
- Nie przeniesiono oryginalnych haseł, profili Wi-Fi, parowań Bluetooth, kluczy SSH/HTTPS, prywatnych katalogów, logów ani tymczasowego dostępu sudo.

## Co sprawdzić na karcie

Rozruch, pierwszy start, Wi-Fi/Ethernet, własne logowanie, ekran i wszystkie przyciski, PTT, karta USB, zestaw Bluetooth, zmiana TG, panel WWW i odsłuch. Rozszerzenie partycji oraz kolejność startu usług także wymagają potwierdzenia na fizycznym sprzęcie.

Przed publicznym wydaniem pozostają testy na czystych kartach i przygotowanie kompletnego pakietu źródeł, licencji oraz informacji o zależnościach. Obsługa opcji personalizacji bezpośrednio w Imagerze może zostać dodana w następnej wersji.

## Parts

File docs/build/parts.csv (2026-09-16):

item | quantity | reference | status
Raspberry Pi | 1 | 3 Model B Rev 1.2 | prototype confirmed
Display | 1 | Adafruit PiTFT 2.2 inch 240x320 HAT | prototype confirmed
USB audio | 1 | Sabrent case approximately 34x23x10 mm | exact product identifier pending
PTT button | 1 | PBS-110 style momentary | exact variant and contacts pending
microSD | 1 | minimum 8 GB for alpha image | physical image boot pending
Power supply and cable | 1 set | external supply | exact model and load test pending
Microphone and playback | 1 audio path | USB audio or Bluetooth | models and wiring pending
Lower screws | 2 | M3x12 countersunk | prototype mechanical reference
Nuts | 2 | M3 5 mm across flats x 2 mm thick | prototype mechanical reference
Display fasteners | 4 screws + 4 spacers | M3x12 screws | screw length confirmed by author; spacer length pending
Printed body | 1 | V32 | STL available
Printed front | 1 | V38 | STL available
Printed button caps | 4 | V11 | STL available
Decorative knobs | 2 | one of each model | STL available
Decorative antenna base | 1 | matching model | STL available
Decorative antenna | 1 | 70 mm | STL available
PTT wires | 2 | approximately 10 cm each | author assembly sequence; individual heat-shrink on joints
Hot glue | as needed | PTT body retention | author assembly sequence

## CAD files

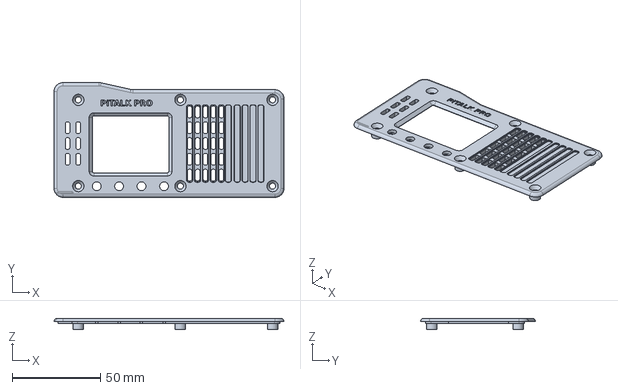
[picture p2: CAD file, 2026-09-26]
step/ec11-v39-v42/02_Front_Panel_V42.step
130.6 x 65.2 x 6.40 mm

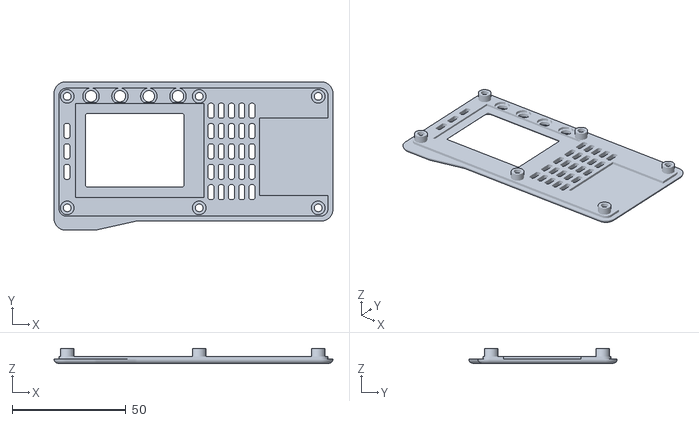
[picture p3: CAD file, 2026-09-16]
stl/02_Flat_Front_Panel_V38.stl
122.6 x 65.2 x 6.40

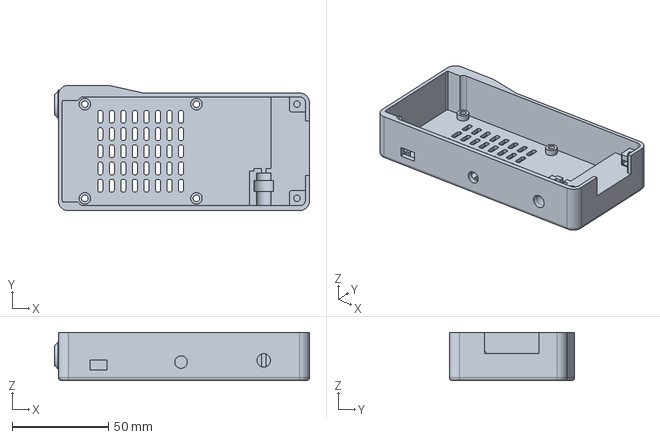
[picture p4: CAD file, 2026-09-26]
step/ec11-v39-v42/01_Body_V39.step
132.6 x 65.2 x 25.0 mm

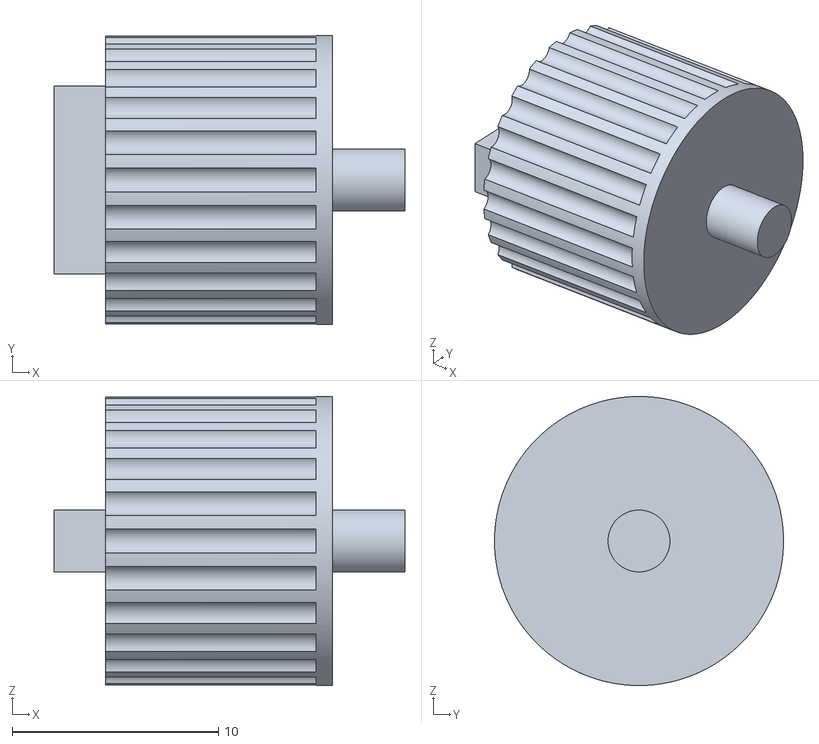
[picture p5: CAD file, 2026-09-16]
stl/05_Control_Knob_2.stl
17.0 x 14.0 x 14.0

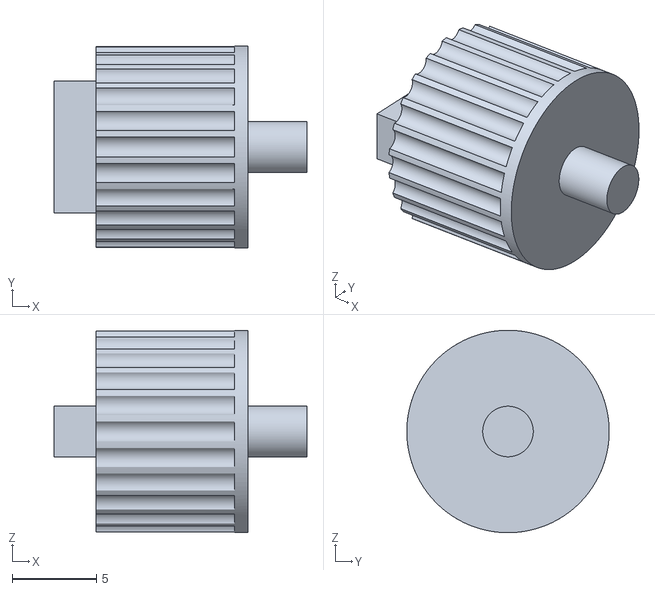
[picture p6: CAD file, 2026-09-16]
stl/04_Control_Knob_1.stl
15.0 x 12.0 x 12.0

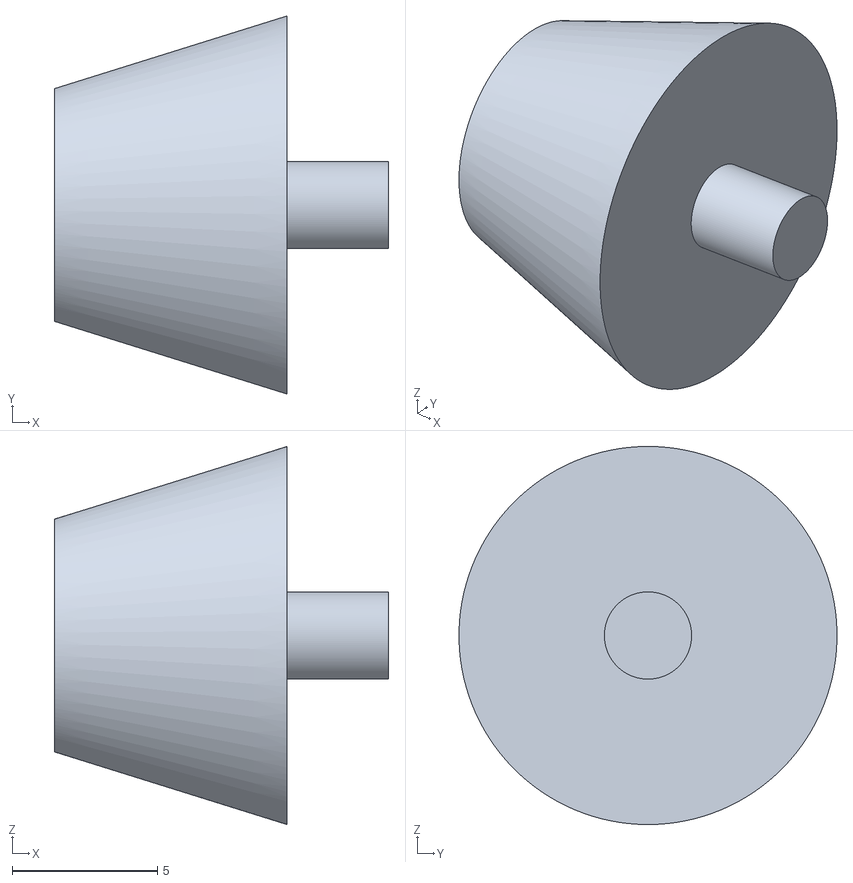
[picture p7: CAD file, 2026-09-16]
stl/PITalk-Final-STL-V39-V42/04_Antenna_Base.stl
11.5 x 13.0 x 13.0

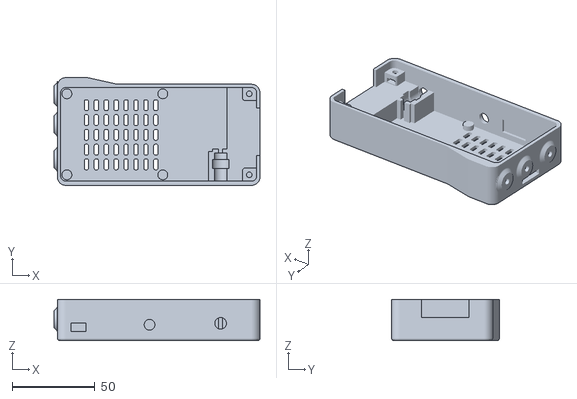
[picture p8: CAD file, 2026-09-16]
stl/01_Body_V32.stl
124.6 x 65.2 x 25.0

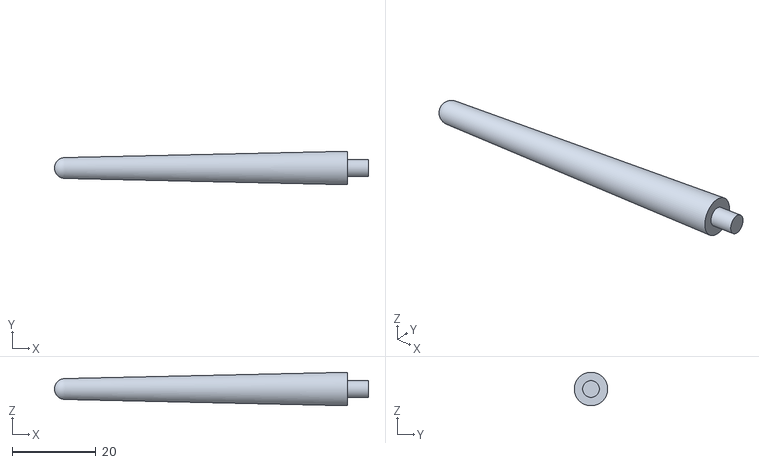
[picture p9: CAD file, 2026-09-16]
stl/PITalk-Final-STL-V39-V42/05_Decorative_Antenna_70mm.stl
75.0 x 8.00 x 8.00

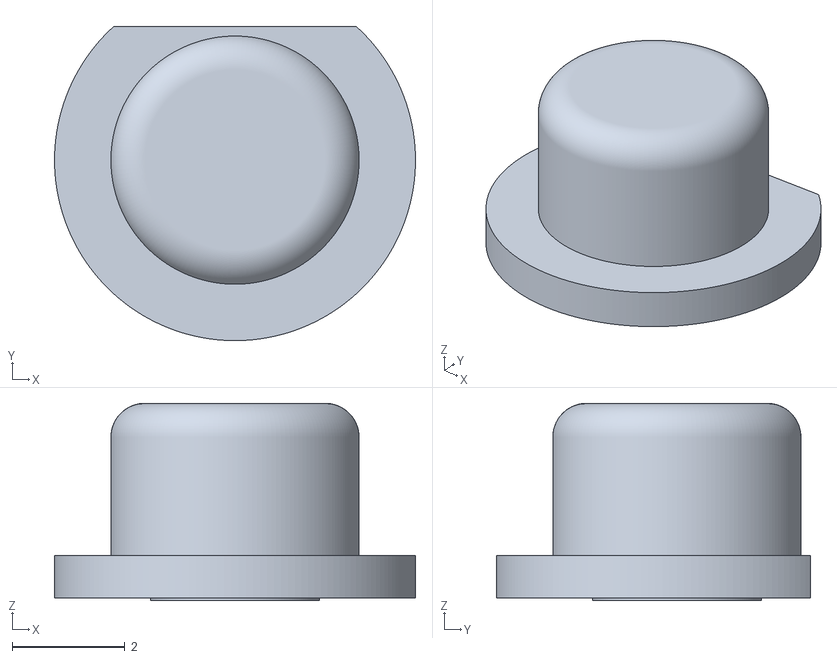
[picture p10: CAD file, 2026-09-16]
stl/PITalk-Final-STL-V39-V42/03_Button_Cap_V11_Print_4.stl
6.40 x 5.57 x 3.50

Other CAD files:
stl/PITalk-Final-STL-V39-V42/02_Front_Panel_V42.stl
stl/PITalk-Final-STL-V39-V42/01_Body_V39.stl

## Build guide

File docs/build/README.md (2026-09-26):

# Zbuduj własny PiTalk Pro

Najnowsza mechanika: [korpus V39 i front V42 pod EC11 — pliki, wymiary i zakres testów](MECHANICAL-EC11.md). Pełny montaż tej wersji wymaga jeszcze sprawdzenia.

Przewodnik dla sprzętu zgodnego z prototypem: Raspberry Pi 3 Model B i PiTFT 2.2 cala. To ścieżka rozwojowa; pełna budowa według tej instrukcji przez drugą osobę nie została jeszcze potwierdzona.

| Etap | Materiały | Wynik, który powinieneś uzyskać |
| --- | --- | --- |
| 1. Sprawdź kompletność | [Status projektu](../project/READINESS.md) | Wiesz, które kroki są potwierdzone, a które wymagają pracy |
| 2. Dobierz części | [Lista sprzętu](HARDWARE.md), [BOM CSV](parts.csv) | Zgodne części i sprawdzone wymiary przed drukiem |
| 3. Wydrukuj i dopasuj | [Instrukcja montażu ze zdjęciami](ASSEMBLY.md), [STL](../../stl/) | Swobodny ruch przycisków i poprawne mocowanie elektroniki |
| 4. Zweryfikuj połączenia | [GPIO i audio](HARDWARE.md#połączenia) | Sprawdzony przycisk, zasilanie i tor audio; brak nieopisanych połączeń |
| 5. Przygotuj system | [Instalacja](SOFTWARE.md) | Własny system i konto, bez danych autora |
| 6. Skonfiguruj terminal | [Pierwsze uruchomienie](SOFTWARE.md#pierwsza-konfiguracja-obrazu-alpha) | Wi-Fi/LAN, panel, własne dane reflektora i wybrany tor audio |
| 7. Sprawdź urządzenie | [Protokół testu](../testing/ACCEPTANCE.md) | Zapisany wynik testów, także po restarcie |
| 8. Zachowaj działającą wersję | [Backupy](../handoff/IMAGE-AND-BACKUPS.md) | Prywatna kopia własnego systemu i opis wersji |

## Zanim rozpoczniesz

Nie zakładaj zgodności innych Raspberry Pi, wyświetlaczy lub podobnie nazwanych kart USB. Zapisz użyte modele i wersję plików STL. Projekt ma programowy PTT do SvxLink; ozdobna antena nie jest anteną nadajnika RF. Rozmowy o zewnętrznym radiotelefonie lub EchoLink nie oznaczają, że taki interfejs jest tu gotowy.

Jeżeli dany krok nie ma pełnej instrukcji, zgłoś brak i dołącz opis rozwiązania po jego sprawdzeniu. Nie przedstawiaj nieprzetestowanej sekwencji poleceń jako sprawdzonej instrukcji budowy.

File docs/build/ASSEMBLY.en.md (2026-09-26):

# PiTalk Pro assembly

This guide illustrates the earlier prototype. For V39/V42, also follow the [EC11 revision assembly differences](MECHANICAL-EC11.md).

[Polski — illustrated guide](ASSEMBLY.md) · [Photo index](../../photos/README.md)

Follow the prototype author's sequence: **assemble the front first**, then the rear enclosure. Work with power disconnected. Prepare four M3×12 LCD screws, four spacers, two M3 nuts and two M3×12 lower closure screws, two wires approximately 10 cm each, heat-shrink tubing and hot glue. Spacer length still needs a recorded measurement.

## Front panel

1. Place the four printed button caps in their slots from inside the front. Check free movement. [Photo](../../photos/IMG_3595.jpeg)
2. Insert four M3×12 screws through the front, with their threads facing the LCD mounting side.
3. Place the LCD board over the screws, with the display facing the window. Align its buttons with the caps. [Photo](../../photos/IMG_3597.jpeg)
4. Align the LCD and gently tighten the screws. Do not distort the board or jam the buttons. [Photo](../../photos/IMG_3598.jpeg)
5. Screw the four spacers onto the exposed threads behind the LCD. Set the completed front aside. [Photo](../../photos/IMG_3601.jpeg)

## Rear enclosure

1. Solder two wires, approximately 10 cm each, to the two PTT button terminals. Insulate each joint separately with heat-shrink tubing. [Photo](../../photos/IMG_3604.jpeg)
2. Fit the PTT button into its side recess in the rear enclosure, with the wires inside. [Photo](../../photos/IMG_3608.jpeg)
3. Secure the button body with hot glue. Keep glue away from the moving plunger and check that it returns when released. [Photo](../../photos/IMG_3611.jpeg)
4. Identify physical header pins 37 and 39. Gently bend them toward the centre of the Raspberry Pi board, as on the prototype, leaving clearance for the PiTFT connector. Do not bend neighbouring pins. [Photo](../../photos/IMG_3613.jpeg)
5. Solder one PTT wire to physical pin 37 (GPIO26) and the other to pin 39 (GND). The photo uses red for 37 and black for 39. Insulate each joint separately with heat-shrink; check for adjacent-pin shorts. [Close-up](../../photos/IMG_3615.jpeg)
6. Before inserting the Pi, install any optional small USB accessories in the lower sockets of the USB stacks, closest to the PCB: Bluetooth dongle, mouse/keyboard receiver or USB storage. Leave space and a port for the sound adapter.
7. Place the Raspberry Pi in the enclosure and align its ports. Route the PTT wires clear of the board supports and front closure. [Photo](../../photos/IMG_3617.jpeg)
8. Insert the two M3 nuts into the lower nut pockets, aligned with the closure screw holes.
9. Insert the prepared microSD card through the access opening. [Access opening](../../photos/IMG_3618.jpeg)
10. Install the USB sound adapter in its intended free port. Check enclosure and connector clearance. [Adapter before fitting](../../photos/IMG_3619.jpeg)
11. Fit the completed front assembly. Align the PiTFT header correctly with the Pi pins and keep the wires clear; do not offset the connector by a row or pin.
12. Tighten the two lower M3×12 screws into the nuts. Tighten gradually without deforming the print. Check all buttons and ports.

## Pin numbering and checks

37 and 39 are **physical header numbers**, not BCM numbers: 37 is GPIO26 and 39 is GND. See the [Raspberry Pi 3 B Rev 1.2 schematic](https://www.raspberrypi.org/documentation/hardware/raspberrypi/schematics/rpi_SCH_3b_1p2_reduced.pdf). Confirm orientation before soldering. With power disconnected, check that PTT is open when released and closes when pressed.

The photo series does not show every operation. There are no separate photos of inserting optional USB accessories, nuts, fitting the audio adapter or closing the finished enclosure. These steps follow the author's written sequence. The photos remain unmodified.

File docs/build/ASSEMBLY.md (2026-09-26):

# Montaż PiTalk Pro — krok po kroku

Ta instrukcja pokazuje wcześniejszy prototyp. Dla najnowszej pary V39/V42 uwzględnij [zmiany montażowe EC11](MECHANICAL-EC11.md).

[English](ASSEMBLY.en.md) · [Lista części](HARDWARE.md) · [Indeks wszystkich zdjęć](../../photos/README.md)

Kolejność podana przez autora prototypu i zestawiona ze zdjęciami `IMG_3595`–`IMG_3619`. **Zaczynamy od kompletnego frontu**, potem montujemy tylną część obudowy. Zdjęcia pokazują kolejne stany, nie każdą czynność osobno; kroki bez zdjęcia wynikają z instrukcji autora.

Montaż i lutowanie wykonuj przy odłączonym zasilaniu. Przygotuj 4 śruby M3×12 do LCD oraz 2 dolne śruby M3×12, 4 dystanse, 2 nakrętki M3, dwa przewody po około 10 cm, koszulki termokurczliwe i klej na gorąco. Długość dystansów pozostaje do uzupełnienia pomiarem.

## Front

### 1. Umieść przyciski w slotach

Połóż front wewnętrzną stroną do góry i włóż cztery drukowane nakładki w ich sloty. Sprawdź, czy każda porusza się swobodnie.

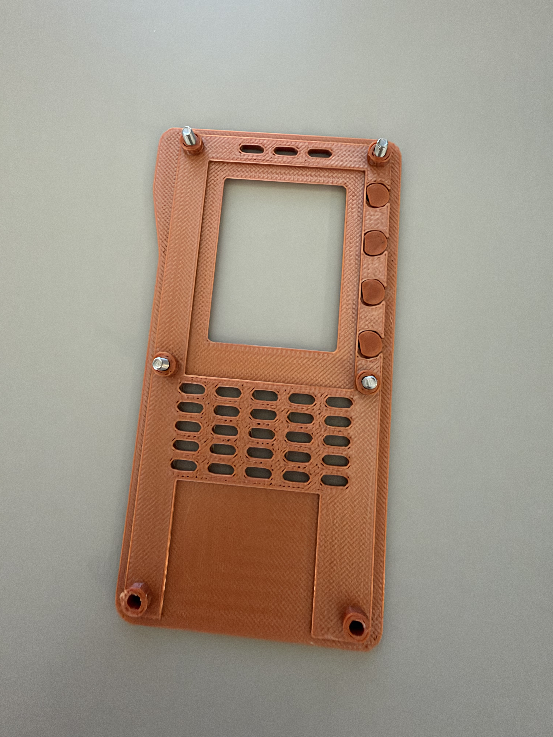
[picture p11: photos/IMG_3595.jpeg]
Umieść przyciski w slotach


### 2. Umieść cztery śruby M3×12 w panelu

Przełóż cztery śruby od zewnętrznej strony frontu, tak aby gwinty wystawały po stronie montażowej LCD.

### 3. Przyłóż ekran LCD

Nałóż płytkę PiTFT na cztery śruby, ekranem w stronę okna frontu. Przyciski płytki muszą pokrywać się z nakładkami.

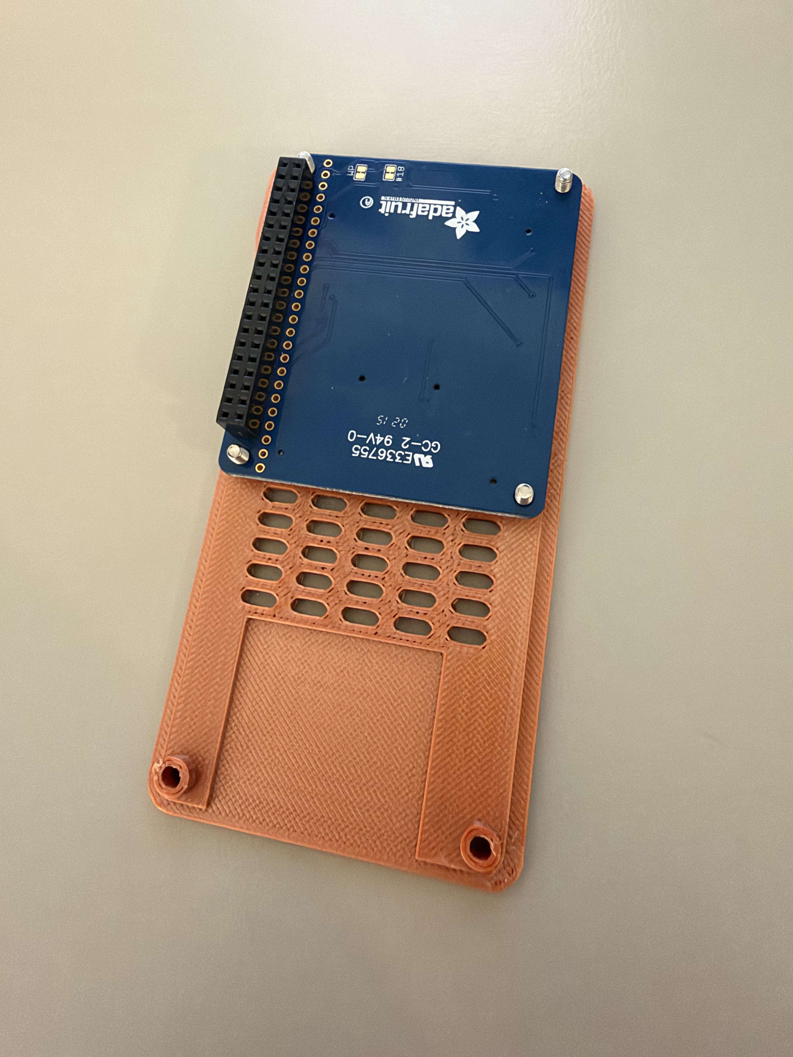
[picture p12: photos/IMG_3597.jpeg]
Przyłóż ekran LCD


### 4. Przykręć śruby

Ustaw LCD równo w oknie i lekko dociągnij cztery śruby. Nie ściskaj płytki ani nie blokuj nakładek przycisków.

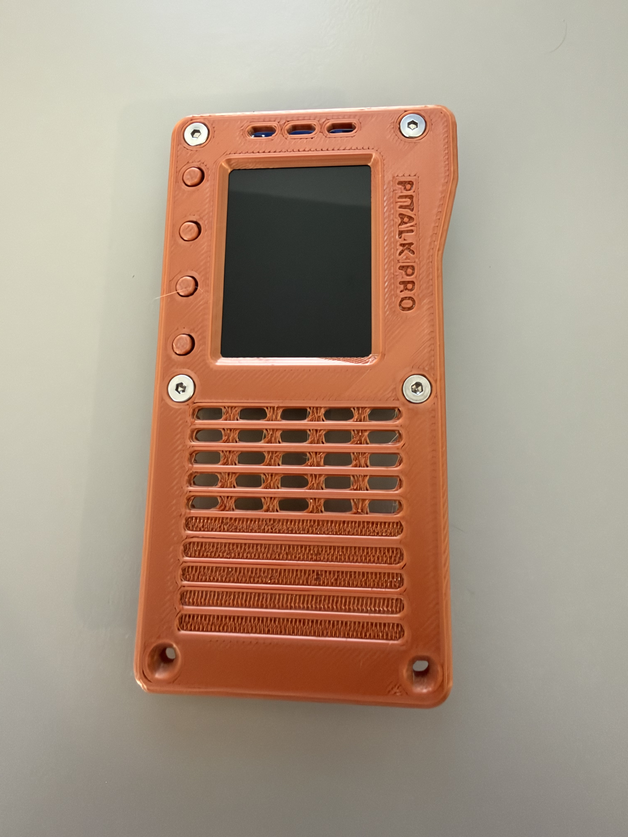
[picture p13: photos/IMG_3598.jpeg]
Przykręć śruby


### 5. Przykręć dystanse

Od strony tylnej płytki przykręć cztery dystanse do wystających gwintów. Gotowy front z ekranem odłóż na bok.

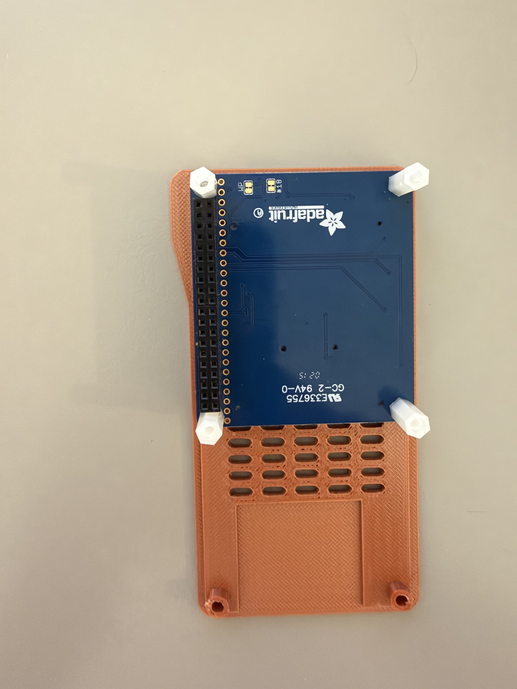
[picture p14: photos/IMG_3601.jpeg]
Przykręć dystanse


## Tylna część obudowy

Boczny element opisany poniżej to chwilowy przycisk PTT.

### 1. Przylutuj przewody do PTT

Przygotuj dwa przewody, każdy długości około 10 cm. Przylutuj po jednym do każdego styku przycisku PTT. Każde połączenie osłoń osobną koszulką termokurczliwą.

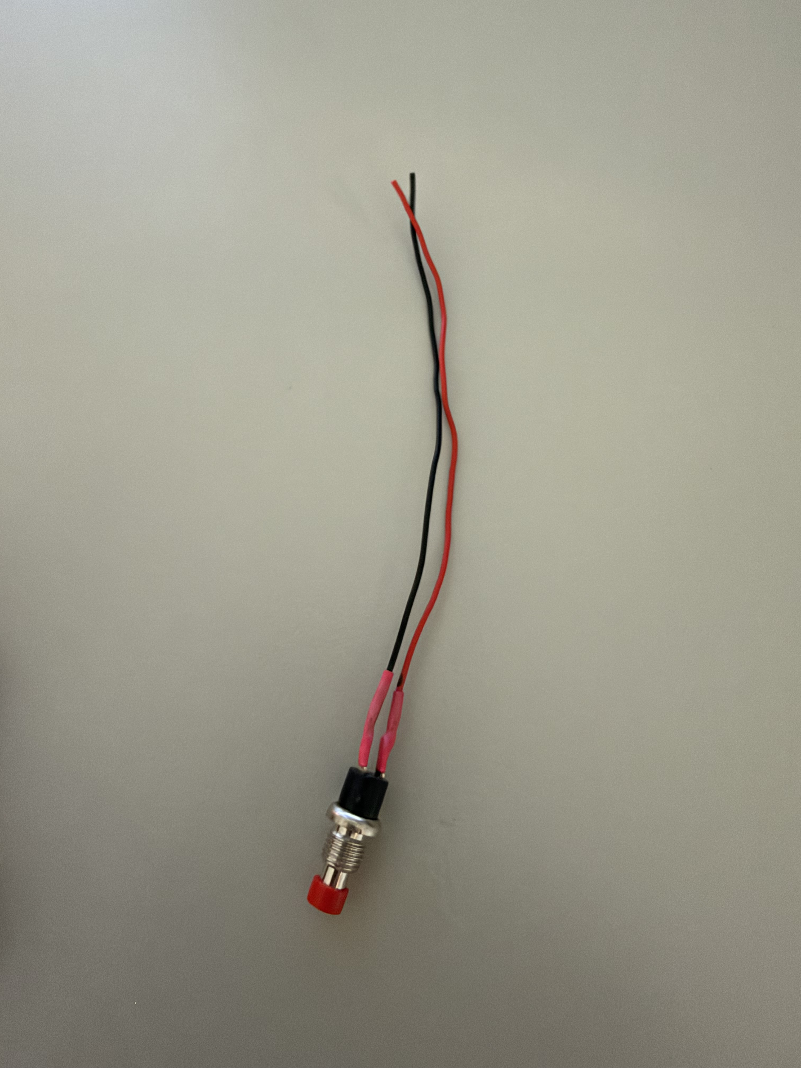
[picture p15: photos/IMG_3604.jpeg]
Przylutuj przewody do PTT


### 2. Zamontuj PTT w obudowie

Umieść przycisk w bocznym gnieździe tylnej części obudowy. Poprowadź przewody do wnętrza, zgodnie z widocznym ułożeniem.

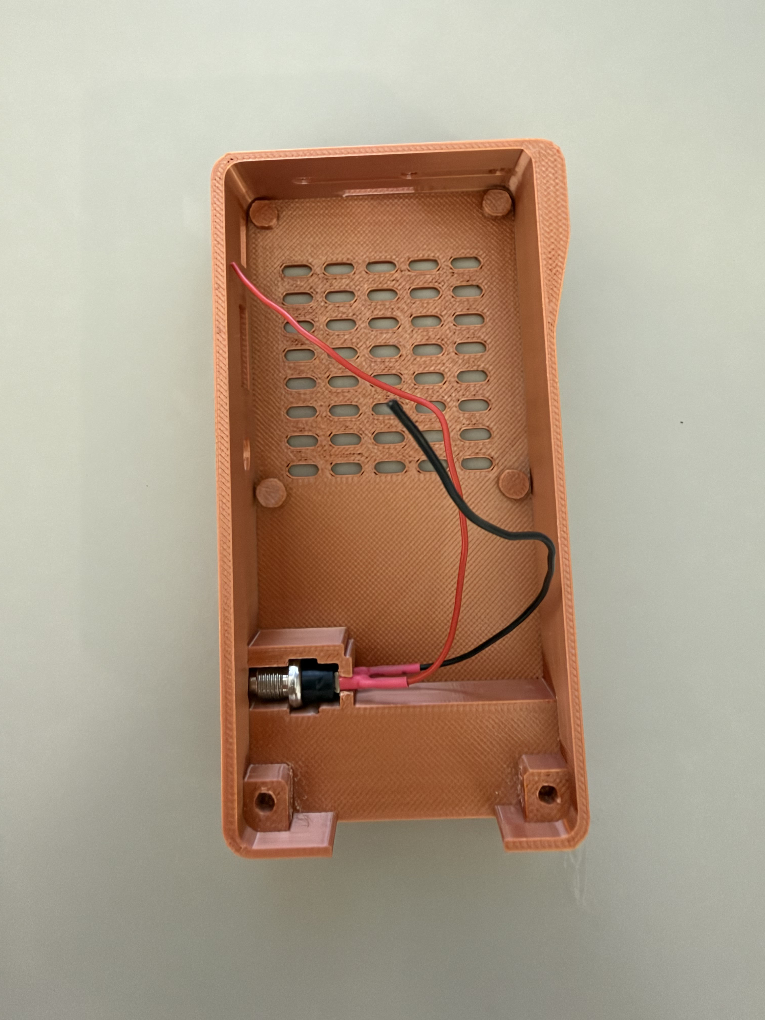
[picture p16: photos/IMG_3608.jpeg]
Zamontuj PTT w obudowie


### 3. Zabezpiecz przycisk gorącym klejem

Unieruchom korpus przycisku klejem na gorąco. Nie zalej ruchomego trzpienia; po ostygnięciu sprawdź, czy przycisk wraca po puszczeniu.

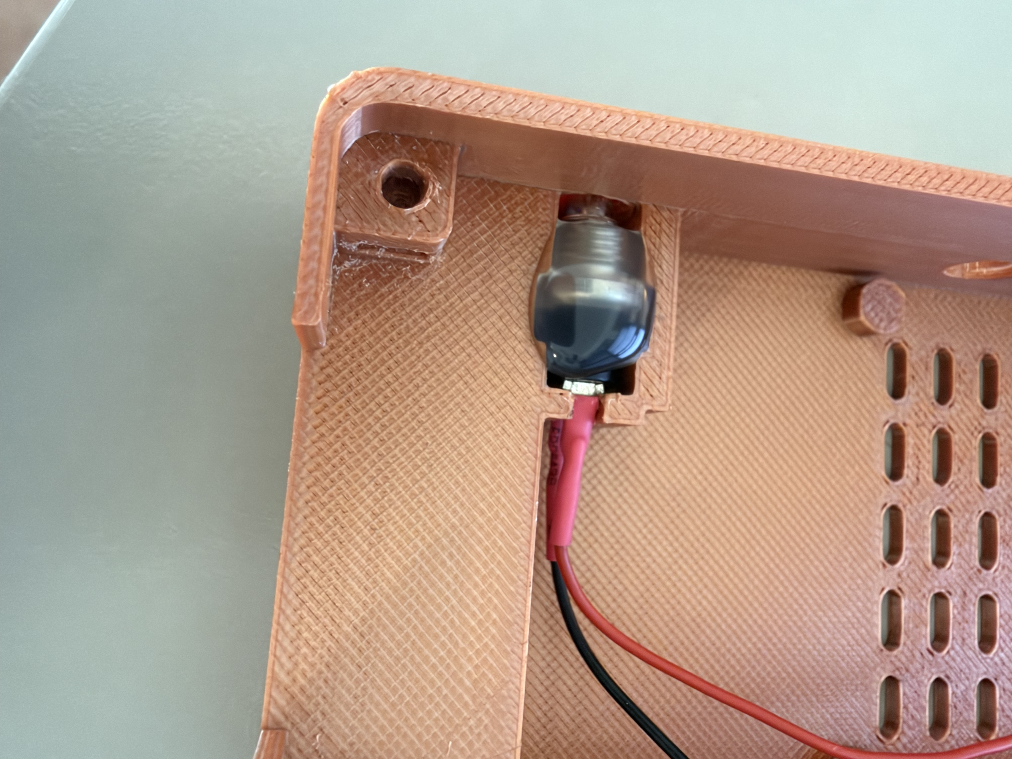
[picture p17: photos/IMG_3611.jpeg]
Zabezpiecz przycisk gorącym klejem


### 4. Wygnij piny 37 i 39 do środka

Przy odłączonym zasilaniu zidentyfikuj fizyczne piny 37 i 39 złącza Raspberry Pi. Delikatnie odegnij je w stronę środka płytki, jak w prototypie, pozostawiając miejsce na złącze PiTFT. Nie odginaj sąsiednich pinów.

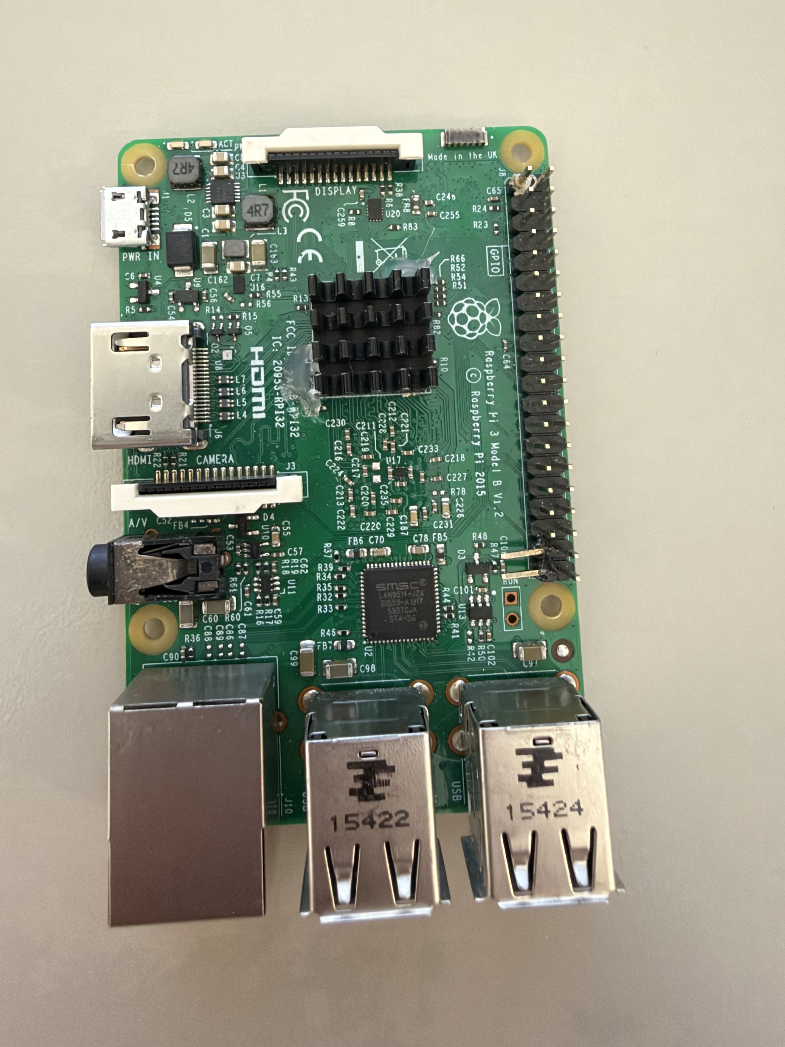
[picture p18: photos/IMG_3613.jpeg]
Wygnij piny 37 i 39 do środka


### 5. Przylutuj PTT do Raspberry Pi i zaizoluj

Przylutuj jeden przewód przycisku do fizycznego pinu 37 (GPIO26), drugi do pinu 39 (GND). Na zdjęciu czerwony przewód prowadzi do 37, czarny do 39. Osłoń oba luty osobnymi koszulkami termokurczliwymi; sprawdź brak zwarć z sąsiednimi pinami.

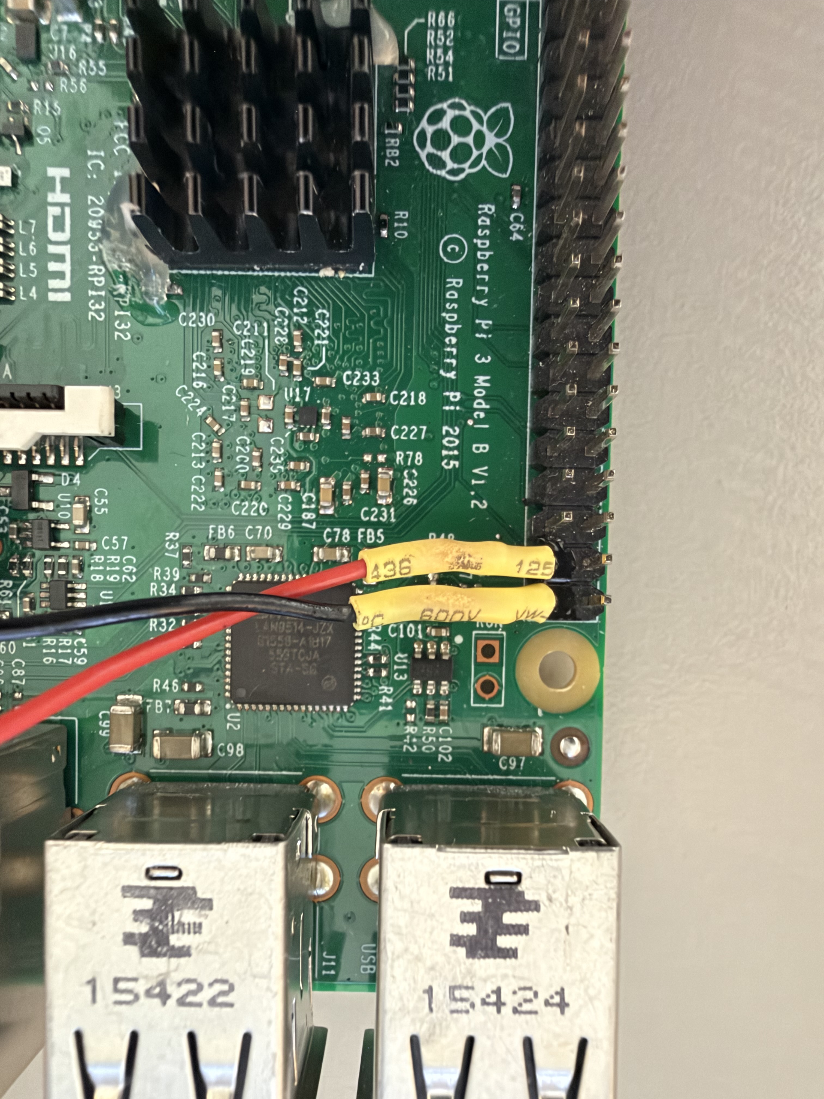
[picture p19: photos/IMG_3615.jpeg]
Przylutuj PTT do Raspberry Pi i zaizoluj


### 6. Włóż opcjonalne akcesoria do dolnych portów USB

Przed umieszczeniem Pi w obudowie włóż potrzebne małe akcesoria do dolnych gniazd stosu USB, czyli gniazd bliższych płytce: np. dongle Bluetooth, odbiornik myszy/klawiatury lub pamięć USB. To krok opcjonalny; zachowaj miejsce na kartę dźwiękową.

### 7. Włóż Raspberry Pi

Umieść płytkę w tylnej części obudowy i dopasuj porty do otworów. Ułóż przewody PTT tak, aby nie były przyciśnięte pod płytką ani nie przeszkadzały w zamknięciu frontu.

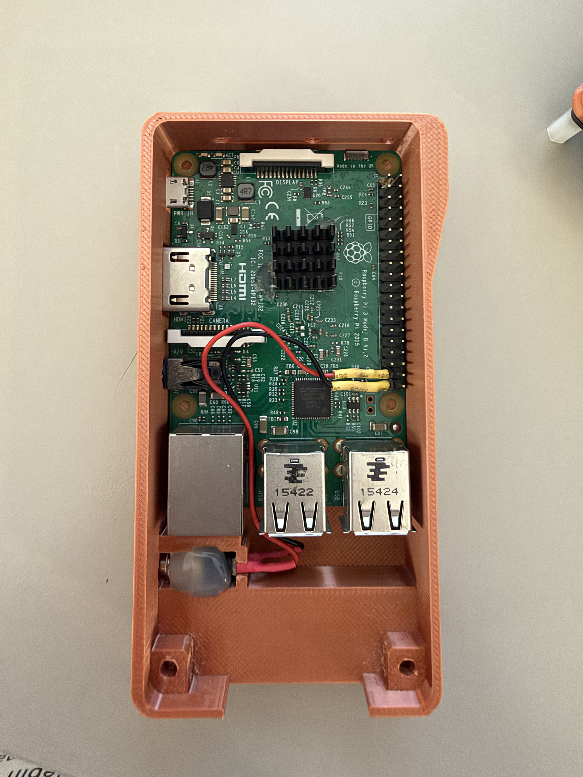
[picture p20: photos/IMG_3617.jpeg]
Włóż Raspberry Pi


### 8. Włóż nakrętki

Wsuń dwie nakrętki M3 w dolne kieszenie mocujące. Ustaw ich otwory w osi śrub, które na końcu zamkną obudowę.

### 9. Włóż kartę microSD

Włóż przygotowaną kartę microSD do Raspberry Pi przez dostępny otwór. Etap przygotowania systemu opisuje osobna instrukcja instalacji.

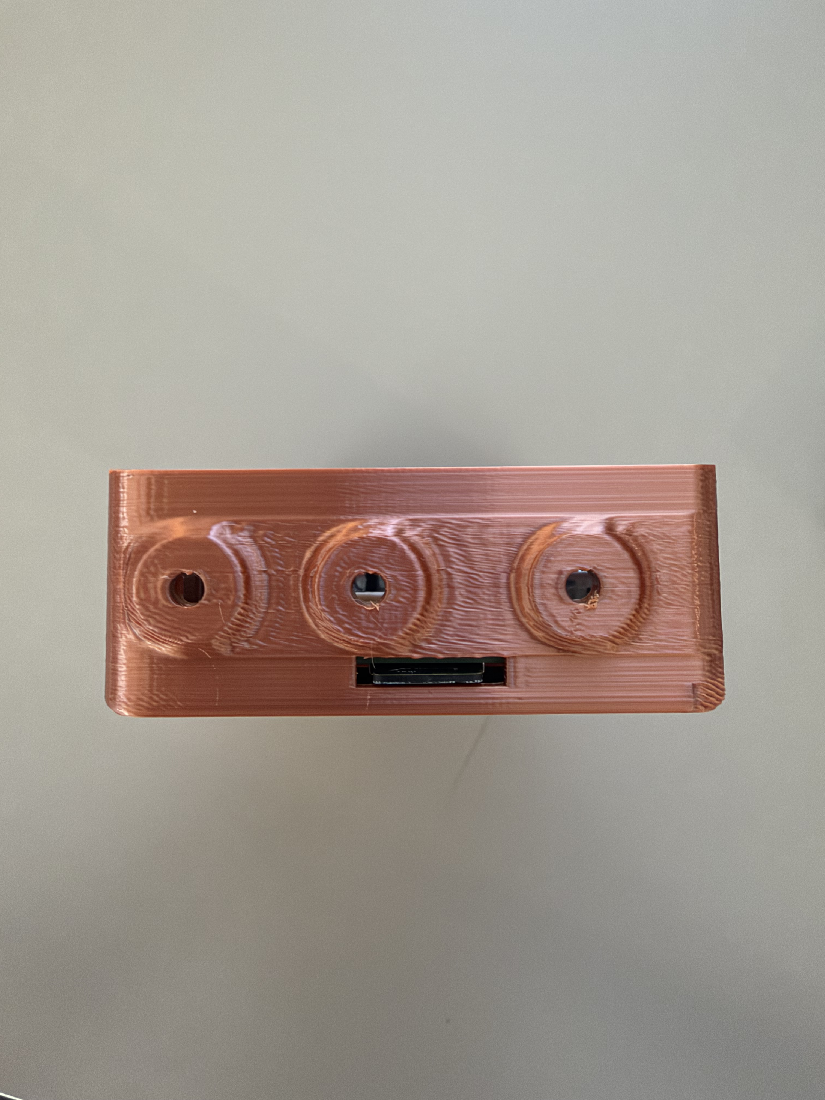
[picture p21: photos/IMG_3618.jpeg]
Włóż kartę microSD


### 10. Zainstaluj kartę dźwiękową

Włóż kartę dźwiękową USB do przeznaczonego dla niej wolnego portu. Sprawdź, czy jej obudowa i złącza mieszczą się bez nacisku.

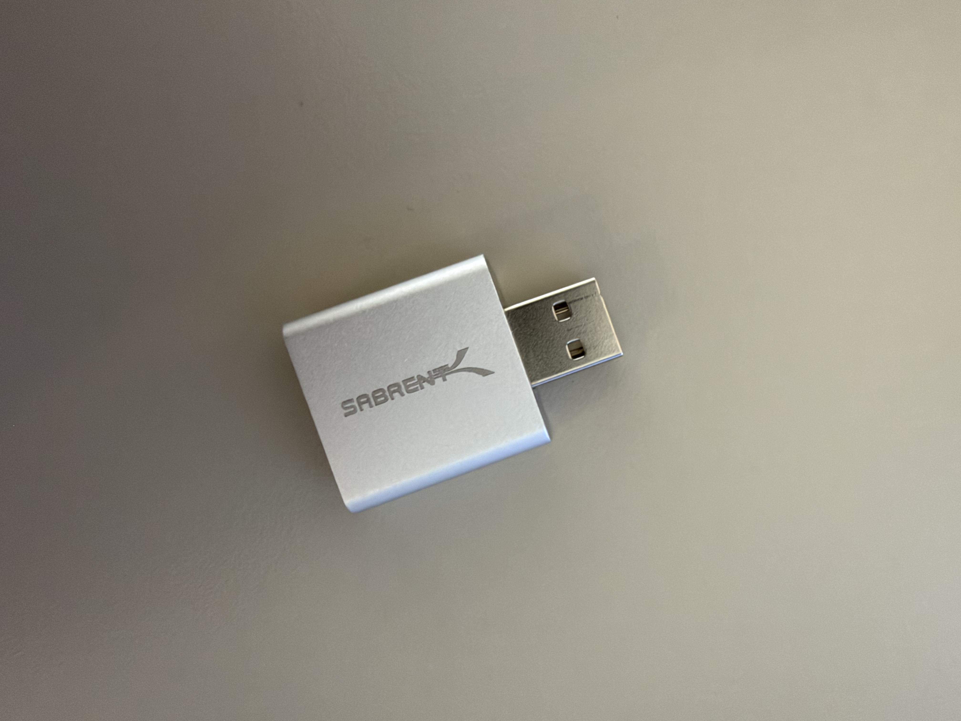
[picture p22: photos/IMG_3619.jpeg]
Zainstaluj kartę dźwiękową


### 11. Zainstaluj front

Przyłóż gotowy zespół frontu z LCD. Wyrównaj złącze PiTFT względem pinów Raspberry Pi, sprawdź przewody PTT i osadź front bez przesunięcia złącza o rząd lub pin.

### 12. Dokręć dolne śruby

Zamknij obudowę dwiema dolnymi śrubami M3×12 w przygotowanych nakrętkach. Dokręcaj stopniowo, bez odkształcania wydruku. Sprawdź ruch wszystkich przycisków i dostęp do portów.

## Numeracja i kontrola PTT

**37 i 39 to fizyczne numery pinów**, a nie numery BCM. Pin 37 odpowiada GPIO26, pin 39 to GND. Numerację można sprawdzić w [schemacie Raspberry Pi 3 B Rev 1.2](https://www.raspberrypi.org/documentation/hardware/raspberrypi/schematics/rpi_SCH_3b_1p2_reduced.pdf). Piny te są na końcu złącza od strony portów USB, w rzędzie bliższym środkowi płytki; przed lutowaniem porównaj orientację ze schematem.

Przy odłączonym zasilaniu sprawdź miernikiem: puszczony PTT nie zwiera przewodów, wciśnięty zwiera je ze sobą. Nie używaj koloru przewodu jako jedynej podstawy identyfikacji pinu. Po montażu przejdź do [instalacji](SOFTWARE.md) i [testu urządzenia](../testing/ACCEPTANCE.md).

## Zakres zdjęć

Seria pokazuje front, dystanse, przygotowanie PTT, jego osadzenie i klejenie, lutowanie do Pi oraz umieszczenie płytki w obudowie. IMG_3618 pokazuje dostęp do gniazda microSD, a IMG_3619 samą kartę dźwiękową. Brakuje osobnych ujęć wkładania akcesoriów USB, nakrętek, instalowania karty audio oraz końcowego zamknięcia obudowy. Nie przypisujemy tym zdjęciom czynności, których nie pokazują.

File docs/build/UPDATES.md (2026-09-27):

# Aktualizacje z ekranu PiTALK

W menu głównym wybierz **System Update**. **Check for updates** odczytuje kanał stable w GitHub. **Install update** wymaga osobnego potwierdzenia; Cancel jest domyślne.

Wersja 1 aktualizuje tylko ekran, obsługę enkodera, regulację głośności i menu aktualizacji. Nie aktualizuje panelu WWW, systemu, samego uprzywilejowanego instalatora ani ustawień urządzenia. Panel WWW ma lokalną konfigurację wymagającą wcześniejszego oddzielenia od kodu. To wydanie aplikacji, nie obraz firmware.

Enkoder: A=BCM5/pin29, B=BCM6/pin31, klik=BCM13/pin33, masa=pin39. Na ekranie głównym obrót zmienia głośność co 5%, klik otwiera menu. W menu obrót przewija, klik zatwierdza; BACK pozostaje na przycisku HAT. Użytkownik potwierdził działanie enkodera; kierunek przywrócono do pierwotnego.

## Instalacja aktualizacji

Urządzenie pobiera `software/updates/stable.json` przez HTTPS, następnie manifest i cztery pliki z oznaczonego tagu `pitalk-vX.Y.Z`. Nie wymaga programu Git ani tokenu do publicznego repozytorium. Weryfikuje SHA-256, listę dozwolonych ścieżek i składnię Pythona przed zmianą. Zaufanie opiera się na HTTPS i kontroli repozytorium; nie ma niezależnego podpisu wydania. Nie zmieniaj opublikowanych tagów.

Instalacja wymaga: braku PTT i RX, aktualnego PID w stanie radia, minimum 50 MiB miejsca. Na życzenie właściciela niskie napięcie nie blokuje instalacji. Awaria sieci podczas pobierania nie zmienia działających plików.

Przed podmianą plików powstaje kopia w `/var/lib/pitalk-update/backup` i trwały dziennik `pending.json`. Po restarcie ekranu helper oczekuje na świeży heartbeat po zapisie framebuffer, należący do bieżącego PID; wymagane jest 20 sekund stabilności w czasie do 75 sekund. Przy błędzie przywraca poprzednie pliki. Po przerwaniu instalacji helper przy starcie odtwarza kopię. To kontrola pracy programu, nie fizycznego obrazu LCD ani jakości audio. Zachowywana jest jedna kopia poprzedniej transakcji.

## Pierwsze wdrożenie i wydania

Pierwsze uruchomienie wymaga administratora: instalacja `pitalk-update.py`, jednostki systemd, czterech plików aplikacji i nadanie katalogowi stanu praw 0700. Zainstalowana wersja jest zapisana przez administratora w `/var/lib/pitalk-update/installed.json`. Nie kopiuj całego rootfs ani przykładów konfiguracji nad urządzenie.

Przy kolejnym wydaniu zmień tag w `release.json`, przelicz SHA-256 czterech plików, wykonaj testy, opublikuj commit i nowy tag; dopiero potem wskaż tag w `stable.json`. Po starcie nowej aplikacji operator sprawdza ekran, menu, enkoder i głośność. Dostęp SSH zachowaj jako drogę naprawy.

## Walidacja

`python3 software/tests/test_update.py`: test manifestu, odrzucenia niedozwolonej ścieżki, zapisu atomowego, instalacji i rollbacku na tymczasowych plikach. Nie są to testy odcięcia zasilania na fizycznym urządzeniu. Pierwszy prototyp zgłasza undervoltage; pełnego cyklu instalacji nowego wydania na urządzeniu nie potwierdzono.

### Wdrożenie prototypu — 2026-09-27

Zainstalowano i włączono usługę aktualizatora za zgodą właściciela. Ekran oraz helper aktywne, bez automatycznych restartów; świeży heartbeat po zapisie obrazu. Sprawdzenie GitHub zwróciło `Up to date`, zainstalowana i dostępna wersja `pitalk-v0.1.0`. Urządzenie nadal zgłasza bieżące undervoltage (`0x50005`); pełnej instalacji kolejnego wydania ani fizycznego rollbacku nie testowano.

### Poprawka interfejsu 0.1.2 — 2026-09-27

Wersja `pitalk-v0.1.2` poprawia układ System Update: nagłówek obok ikony powrotu, wspólne zaznaczenie, osobne miejsce na potwierdzenie i maksymalnie trzy linie komunikatu. Wybierz Check for updates, następnie Install update i Install now. Po instalacji sprawdź Current: pitalk-v0.1.2 oraz brak nakładania napisów. Rendery sprawdzono lokalnie; instalacja i wygląd na fizycznym LCD wymagają potwierdzenia właściciela.

### Panel WWW — przygotowany 2026-09-27

System zawiera sekcję System Update: wersje, ręczne sprawdzenie, potwierdzenie instalacji i status odświeżany w tle. API wymaga sesji, operacje POST także CSRF; używa istniejącego ograniczonego helpera. Brak helpera jest widoczny jako niedostępność bez blokowania pozostałego panelu. Sprawdzanie przy starcie urządzenia i monit LCD nie są jeszcze zaimplementowane.

Właściciel potwierdził działanie aktualizacji 0.1.2 z terminala. GitHub + menu urządzenia to uzgodniony kanał aktualizacji. Obecna lista czterech plików nie obejmuje WWW: ta zmiana panelu nie jest jeszcze wdrożona ani oferowana przez stable.json. Rozszerzenie instalatora wymaga osobnej migracji; nie wolno nadpisać prywatnego filtra LAN przykładowym server.py z repozytorium.

### Rozszerzony instalator i wydanie 0.1.3

Jednorazowa migracja prototypu 2026-09-27 zachowała filtr LAN w `/etc/sqlink-web/access.json` i rozszerzyła helper o siedem plików WWW (łącznie 11 plików wydania). Usługa działa; kopia poprzedniego helpera i unitu jest w `/var/backups/pitalk-web-bootstrap-20260927-194540`. Aplikacja pozostała 0.1.2 do instalacji z menu.

0.1.3 dostarcza panel WWW z aktualizacjami. Instalacja restartuje ekran i WWW (sesja przeglądarki oraz odsłuch zostaną przerwane); kontroluje heartbeat ekranu, aktywność WWW i odpowiedź HTTPS przez 20 sekund. W razie błędu przywraca wszystkie pliki transakcji. Stare wydania czteroplikowe pozostają obsługiwane. Stary helper nie zainstaluje wydania 11-plikowego: wymaga najpierw migracji administracyjnej.

Na nowym urządzeniu utwórz `/etc/sqlink-web/access.json` zgodnie z `software/examples/sqlink-web-access.json.example`, ustawiając rzeczywistą podsieć i dozwolone nazwy. Brak konfiguracji blokuje dostęp, nie otwiera panelu. Plik jest poza wydaniem i nie jest nadpisywany przez update. Fizyczny test instalacji 0.1.3 oczekuje na operatora. Automatyczny monit po starcie nadal nie jest częścią tej wersji.

### System Info — 0.1.4

Dodano zakładkę WWW System Info: wersja zainstalowana i ostatnio sprawdzona, model, hostname, OS, kernel, architektura, uptime, temperatura CPU oraz bieżące i historyczne flagi napięcia/throttlingu. Dane są migawką odświeżaną przy otwarciu lub przyciskiem Refresh. Brak źródła oznacza Unavailable. API wymaga logowania. Testy obejmują 0x0, 0x50000, 0x50005 i niedostępne czujniki; wygląd i odczyty na fizycznym urządzeniu wymagają potwierdzenia po instalacji. Wydanie korzysta z rozszerzonego aktualizatora WWW.

### System Info na PiTFT — 0.1.5

Menu urządzenia ma trzy strony: Software, Hardware, Power status. UP/DOWN lub obrót enkodera zmienia stronę, ENTER odświeża, BACK wraca do menu. Odczyty odbywają się w tle, także co 10 sekund podczas otwartego okna. Niedostępne wartości oznaczono Unavailable. Sprawdzono rendery 240×320 i składnię; fizyczny wygląd pozostaje do potwierdzenia po instalacji. Nie wymaga kolejnej migracji helpera.

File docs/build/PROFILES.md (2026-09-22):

# Profile reflektorów — SQLink, Fala i własne serwery

PiTalk Pro przechowuje do 12 profili zgodnych ze SvxReflector. W danej chwili działa jedno połączenie. Każdy profil ma własne: nazwę, host, port, login/znak, hasło, domyślną TG, monitorowane TG oraz czas powrotu do monitorowania. Wi-Fi, Bluetooth i poziomy audio są wspólne.

## Obsługa

- Ekran: **Main Menu → User** otwiera **Profiles**. UP/DOWN wybiera profil, ENTER otwiera jego działania, BACK wraca. **Add profile** tworzy nowy profil.
- Panel: **User → Profiles** (`/#user`). Dostępne są **Add profile, Edit, Activate, Set default, Delete**.
- **Save profile** zapisuje ustawienia bez rozłączania. Zmiany aktywnego profilu wymagają **Activate / Apply & activate**. Domyślny profil podczas kolejnego rozruchu używa swoich zapisanych ustawień.
- **Activate** wymaga hosta, portu, loginu i hasła, blokuje przełączenie podczas PTT/RX, zmienia konfigurację i restartuje SvxLink. Czeka do około 20 sekund na potwierdzenie uwierzytelnienia po restarcie. Przy niepowodzeniu odtwarza poprzednią konfigurację i uruchamia ją ponownie.
- **Set default** nie przełącza aktualnego połączenia. Wskazuje profil stosowany przed uruchomieniem SvxLink przy następnym starcie urządzenia. Nie restartuje urządzenia. Weryfikacja połączenia i powrót do poprzedniego profilu dotyczy aktywacji z menu/API; usługa rozruchowa tylko przygotowuje konfigurację i nie sprawdza dostępności serwera.
- Nie można usunąć aktywnego ani domyślnego profilu. Najpierw wybierz inny. Usunięcie ma chroniony backup na urządzeniu.
- Puste pole hasła podczas edycji zachowuje istniejące hasło. Formularze nie odczytują go z urządzenia. Aby użyć innych danych, wpisz nowe hasło.

## Pierwsze uruchomienie i Fala

Migracja importuje aktualną konfigurację do profilu **SQLink**, ustawia go jako aktywny/domyślny i nie zmienia działającego połączenia. Profil **Fala** powstaje z hostem `fala.zasieg.pl`, pustym portem, loginem i hasłem. Nie kopiuje danych konta SQLink. Uzupełnij właściwy port i konto po przygotowaniu własnego serwera; dopiero wtedy można go aktywować.

**Station directory** określa źródło nazw TG i informacji o stacjach. **SQLink API** korzysta z istniejącego API SQLink. **None — local TG numbers** pokazuje lokalnie skonfigurowane TG i nie pobiera danych SQLink. Fala domyślnie używa None; jej API wymaga osobnej integracji po udostępnieniu. W panelu można wpisać dowolny numer TG. Na PiTFT lista pochodzi z domyślnej i monitorowanych TG; przy pustej liście pozostaje pozycja Monitor (TG 0).

Nazwa faktycznie zastosowanego profilu jest widoczna w nagłówku ekranu głównego, wyśrodkowana pod znakiem wywoławczym, oraz w nagłówku WWW. Długie nazwy są skracane wielokropkiem do dostępnej szerokości. Wybranie pozycji do edycji nie zmienia aktywnego profilu.

## Pliki i uprawnienia

| Ścieżka na Pi | Zawartość |
| --- | --- |
| `/var/lib/sqlink-profiles/profiles.json` | Baza profili, **z hasłami**; root, tryb 600, katalog 700 |
| `/var/lib/sqlink-profiles/pending.json` | Prywatny dziennik transakcji, tylko podczas przełączania; umożliwia odtworzenie po przerwaniu procesu |
| `/var/lib/sqlink-profile-state/active.json` | Publiczne metadane zastosowanego profilu, bez loginu i hasła; tryb 644 |
| `/etc/svxlink/svxlink.conf` | Konfiguracja aktualnego połączenia; istniejące prawa zachowane |
| `/var/backups/sqlink-profiles/` | Prywatne kopie konfiguracji i bazy przed aktywacją/usunięciem; pliki 600 |
| `/usr/local/sbin/sqlink_profiles.py` | Operacje profili wykonywane przez helper jako root |
| `/etc/systemd/system/sqlink-profiles.service` | Zastosowanie domyślnego profilu przy rozruchu |

Baza nie jest szyfrowana: bezpieczeństwo opiera się na uprawnieniach systemowych. Kopie zawierające hasła i klucze nie należą do repozytorium ani publicznego obrazu SD. Publiczny plik stanu nie zawiera danych uwierzytelniających.

## Integracja i aktualizacja

PiTFT i WWW korzystają z tego samego socketu helpera Wi-Fi. Akcje: `profiles_snapshot`, `profiles_save`, `profiles_activate`, `profiles_default`, `profiles_delete`. Zapis wymaga aktualnej rewizji, co chroni przed nadpisaniem zmian z drugiego interfejsu. Web API `/api/profiles` używa istniejącej sesji; POST wymaga CSRF. Stary zapis `user_save` jest zablokowany, aby nie omijał bazy profili.

Do instalacji potrzebne są pliki wymienione w `software/profiles-release.json`, istniejący helper, standardowe zależności Python/Pillow i systemd. Włącz `sqlink-profiles.service` po wgraniu modułów i wykonaniu migracji. Nie kopiuj całego rootfs na istniejące urządzenie: `server.py` w repozytorium ma przykładowy filtr sieci LAN.

`software/manifest.json` zachowuje pochodzenie pierwszego eksportu; `software/profiles-release.json` zawiera sumy tej aktualizacji. Obraz alpha-1 nie został przebudowany i nie zawiera profili.

## Sprawdzenia wykonane 22 września 2026

- 12 testów backendu: import bez ujawniania haseł, niezależność danych Fali, walidacja, niepełny profil, rewizje, usuwanie, PTT/RX, przełączanie, przywrócenie po nieudanym połączeniu, domyślny profil i zachowanie pozostałej konfiguracji.
- 3 testy UI/API: renderowanie ekranów PiTFT, klawiatura/nawigacja/anulowanie i brak pobierania API SQLink dla Fali.
- Symulacja WWW: lista, zablokowane działania, edycja i zapis, pomijanie pustego hasła, dodawanie i układ mobilny.
- Na prototypie: import SQLink, profil Fala bez danych, zapis/usunięcie tymczasowego profilu, odrzucenie aktywacji niepełnego profilu, renderowanie menu, ochrona HTTP 401 i aktywne usługi. Konfiguracja SvxLink i jego PID pozostały niezmienione podczas wdrożenia.
- Podczas końcowego sprawdzenia profil Fala był już uzupełniony i aktywny; lokalny stan SvxLink potwierdził połączenie. Domyślnym na rozruch nadal pozostawał SQLink. Nie eksportowano nowych danych logowania.
- Do sprawdzenia pozostają audio i TG Fali, powrót do SQLink, fizyczne przyciski oraz rozruch z innym profilem domyślnym.

Testy: `python3 software/tests/test_profiles.py`, `python3 software/tests/test_profiles_ui.py`. Pythonowe testy menu wymagają Pillow i czcionki DejaVu (Linux) lub Arial (macOS).

## Przywracanie poprzedniej wersji

Przed ręcznym odtwarzaniem zwolnij PTT i poczekaj na koniec RX. Zachowaj dodatkową kopię bieżącej bazy, jeśli po wdrożeniu dodano konta. Zatrzymaj panel, ekran i helper Wi-Fi, wyłącz usługę `sqlink-profiles.service`, odtwórz poprzednie wersje plików objętych aktualizacją z backupu kodu i wykonaj daemon-reload. Jeżeli od wdrożenia przełączano profile, odtwórz też konfigurację SvxLink z odpowiadającego backupu prywatnego, zachowując właściciela i prawa. Uruchom potrzebne usługi i sprawdź połączenie. Nie usuwaj prywatnej bazy ani backupów podczas diagnozy. Ta procedura ręczna nie była wykonana na prototypie; automatyczne przywrócenie po nieudanej aktywacji sprawdzono w testach z atrapą połączenia.

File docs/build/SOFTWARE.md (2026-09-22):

# Instalacja i pierwsze uruchomienie

## Wybierz właściwą ścieżkę

| Ścieżka | Stan |
| --- | --- |
| Gotowy obraz dla nowej karty | Plik alpha istnieje lokalnie u autora; kontrole pliku przeszły, test rozruchu nie został wykonany. Brak publicznego pliku wydania. |
| Instalacja od czystego systemu | Eksport kodu i przykłady są dostępne. Nie ma kompletnego, przetestowanego instalatora ani przypiętej listy pakietów. |
| Zmiana istniejącego PiTalk Pro | Dla rozwijających prototyp: wąskie wdrożenie wybranych plików po odczytaniu bieżącej konfiguracji. |

**Pobranie repozytorium nie daje jeszcze gotowego do wgrania firmware.** Katalog `software/rootfs/` nie jest pełnym systemem i nie powinien być kopiowany zbiorczo na Raspberry Pi.

## Pierwsza konfiguracja obrazu alpha

Jeżeli otrzymałeś obraz od autora do testów, użyj [instrukcji alpha](../../software/image-tools/IMAGE-INSTALL-PL.md) oraz odpowiadającego mu pliku SHA256SUMS. Opublikowane wydanie powinno w przyszłości zawierać obraz, jego sumę, numer wersji i wyniki testów razem. Nie używaj obrazu skonfigurowanego wcześniej przez inną osobę jej hasłami.

Skrót procesu:

1. Zapisz obraz na osobnej karcie minimum 8 GB w Raspberry Pi Imager, używając własnego obrazu. W tej wersji pomiń personalizację Imagera.
2. Otwórz `pitalk-setup.json` na bootfs i ustaw własne `system_password` zgodnie z instrukcją. Zachowaj poprawny JSON.
3. Hostname domyślnie `pitalk-pro`. Przy kilku urządzeniach w jednej sieci nadaj każdemu inną nazwę.
4. Wpisz Wi-Fi lub użyj LAN. Opcjonalnie wpisz własne dane reflektora; konto reflektora trzeba posiadać niezależnie od tego projektu.
5. Po starcie sprawdź wynik konfiguracji i dostęp do `https://pitalk-pro.local:8443`. Gdy mDNS nie działa, użyj IP z routera/menu.
6. Zaloguj się jako `sqlink` własnym hasłem systemowym. W razie potrzeby skonfiguruj User, Audio i Wi-Fi na urządzeniu lub w panelu.
7. Wypełnij [protokół testu](../testing/ACCEPTANCE.md), w tym ponowny rozruch.

Hasło systemowe do panelu/SSH oraz hasło reflektora to różne dane. Obraz nie tworzy konta na serwerze SQLink. Funkcja zmiany hosta reflektora nie oznacza jeszcze pełnej niezależności od SQLink: adresy API nazw TG i statusu również wymagają przeglądu przy użyciu własnego serwera.

## Czego brakuje do instalacji od czystego OS

Potrzebny jest sprawdzony proces obejmujący:

- wersję bazowego OS i pakietów;
- konto aplikacji, grupy i sesję audio; obecnie część ścieżek zakłada UID 1002;
- PiTFT/framebuffer, uprawnienia GPIO i mapowanie programowego squelcha;
- PipeWire/WirePlumber/BlueZ oraz poprawne wejście i wyjście audio;
- SvxLink, konfigurację logik i handler zdarzeń;
- helpery, sockety i zależności systemd;
- PAM, własny certyfikat HTTPS i filtr lokalnego dostępu dopasowany do sieci;
- generowanie własnej tożsamości urządzenia i sposób aktualizacji/wycofania zmian.

Źródłem szczegółów są [architektura](../handoff/ARCHITECTURE.md), [obsługa](../handoff/OPERATIONS.md) i pliki kodu. Lista powyżej jest zakresem brakującego instalatora, nie sekwencją poleceń do wykonania.

## Gdy pojawi się problem

Nie zaczynaj od ponownego wgrywania systemu. Rozdziel diagnostykę: zasilanie/rozruch, ekran, sieć lokalna, usługi, logowanie do reflektora, wejście/wyjście audio. OFFLINE przy działającym panelu może oznaczać problem połączenia SvxLink, a nie brak Wi-Fi. Opisz objaw i etap testu zgodnie z [CONTRIBUTING.md](../../CONTRIBUTING.md).

## Diagnostyka audio w panelu

Instrukcja i zależności: [test głośnika i mikrofonu](AUDIO-TESTS.md). Funkcja dodana po przygotowaniu obrazu alpha-1.

## Profile reflektorów

[Profile SQLink, Fala i własne serwery](PROFILES.md): menu i WWW, zapis haseł, aktywacja, profil domyślny, instalacja i ograniczenia. Aktualizacja z 22 września 2026, poza obrazem alpha-1.

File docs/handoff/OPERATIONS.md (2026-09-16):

# Obsługa, konfiguracja i dalszy rozwój

## Istotne lokalizacje na urządzeniu

| Lokalizacja | Znaczenie |
| --- | --- |
| `/etc/svxlink/svxlink.conf` | Callsign, hasło reflektora, TG, audio i logika; plik prywatny |
| `/var/backups/sqlink-user/` | Kopie konfiguracji użytkownika, mogą zawierać hasła |
| `/etc/NetworkManager/system-connections/` | Zapisane Wi-Fi, właściciel root, pliki 600 |
| `/var/lib/sqlink-display/settings.json` | Kolory, jasność i timeout menu |
| `/var/lib/sqlink-bluetooth/preferences.json` | Preferencje Bluetooth |
| `/var/lib/bluetooth/` | Systemowe parowania; nie eksportować |
| `/run/sqlink-wifi/control.sock` | Helper Wi-Fi i konfiguracji użytkownika |
| `/run/sqlink-bluetooth/control.sock` | Helper Bluetooth i audio |
| `/run/user/1002/pulse/native` | Socket zgodności PulseAudio dla sesji sqlink |
| `/dev/shm/sqlink-radio-state` | Bieżąca TG / RX / callsign; dane nietrwałe |
| `/var/log/svxlink` | Log SvxLink |
| `/etc/sqlink-web/cert.pem`, `key.pem` | Certyfikat HTTPS i prywatny klucz |
| `/etc/pam.d/sqlink-web` | Uwierzytelnianie panelu kontem systemowym |

Hasło systemowe i hasło reflektora są niezależne. Panel używa konta systemowego `sqlink`. Hasło reflektora pozostaje w chronionym pliku SvxLink; UI nie powinien zwracać go klientowi. Zapis przez helper tworzy kopię i stosuje konfigurację. Nie używaj `cat` na aktywnej konfiguracji do diagnostyki wymagającej tylko jednego niesekretnego pola.

## Zależności

System Linux ARM64 z systemd, SvxLink, NetworkManager (`nmcli`), BlueZ, PipeWire z kompatybilnością PulseAudio, WirePlumber, narzędzia `pactl`/`parec`, Python 3, Pillow, lgpio, bindings D-Bus/GLib używane przez helper Bluetooth, czcionki DejaVu i Avahi dla `.local`. To zestaw zależności funkcjonalnych; repozytorium nie ma jeszcze zamkniętej listy wersji ani w pełni automatycznego instalatora od czystego OS.

Konto `sqlink` ma UID/GID 1002 w prototypie i dodatkowe grupy audio/gpio/video. Usługi odwołują się do sesji użytkownika. Konfiguracja headless WirePlumber wyłącza seat-monitoring dla Bluetooth. Dołączony przykład odtwarza tę poprawkę; nie jest eksportem katalogu domowego ani tokenów audio.

## Diagnostyka

Najpierw odczyty, potem zmiany. Sprawdzaj status usług, krótki wycinek logu, stan interfejsów i aktualny domyślny sink/source. Zanonimizuj logi przed dodaniem do repozytorium.

Przykłady odczytów na Pi:

```sh
systemctl is-active svxlink sqlink-screen sqlink-web sqlink-ptt-button
nmcli device status
ip -br addr
hostnamectl --static
```

Polecenia `pactl` wykonuj w sesji `sqlink`, z właściwym `XDG_RUNTIME_DIR`. Wynik w sesji root bez środowiska audio może być mylący. W przypadku problemów z odsłuchem sprawdź także `PULSE_SERVER` i bind mount z drop-in usługi WWW.

Gdy panel odmawia wejścia po zmianie nazwy/IP, sprawdź `local_access()` w `server.py`, mDNS/Avahi oraz certyfikat. Samo `hostnamectl` nie aktualizuje wszystkich list dozwolonych hostów aplikacji.

## Małe wdrożenie na istniejący prototyp

1. Ustal zakres zmiany i odczytaj aktualne pliki urządzenia; snapshot może być starszy.
2. Zapisz kopię tylko plików objętych zmianą, z uprawnieniami chroniącymi konfigurację.
3. Zmodyfikuj i sprawdź składnię lokalnie; nie importuj bezpośrednio modułów uruchamiających sprzęt.
4. Przenieś wybrane pliki, zachowując właścicieli i tryby. Nie kopiuj szablonów nad aktywne hasła/Wi-Fi.
5. Restartuj wyłącznie potrzebną usługę. Po zmianie unitów wykonaj daemon-reload. Restart serwera WWW unieważnia jego sesje w pamięci i zatrzymuje odsłuch.
6. Zweryfikuj usługę, log i konkretny przepływ. Przy błędzie przywróć kopię, restartuj tę samą usługę i ponownie sprawdź.

Nie ma tu polecenia „wdroż wszystko”, bo mogłoby nadpisać konfigurację lub zablokować dostęp. Zlecone zmiany można wdrażać samodzielnie po sprawdzeniu tych zależności.

## Lokalne kontrole

`software/check-source.py` sprawdza składnię Pythona bez uruchamiania sprzętu oraz prosty filtr sekretów. JavaScript można sprawdzić `node --check` dla każdego pliku `.js`. Skrypty shell — `bash -n`. To kontrole statyczne, nie dowód poprawnego działania GPIO, audio, sieci czy rozruchu.

Symulacja `software/image-tools/test-firstboot.py` używa plików tymczasowych i zastępuje polecenia systemowe. Nie uruchamiaj samego `firstboot.py` ani `sanitize.py` na systemie roboczym. Są przeznaczone dla przygotowanego środowiska obrazu.

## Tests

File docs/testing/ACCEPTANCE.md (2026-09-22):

# Protokół testu własnego egzemplarza

Skopiuj ten dokument do raportu dla konkretnego egzemplarza i wersji. Puste pola oznaczają brak testu, nie sukces. Używaj wyników PASS / FAIL / NIE TESTOWANO i dodaj dowód lub krótką obserwację. Nie zamieszczaj haseł, prywatnych kluczy, cookies ani nieoczyszczonych logów.

- Data:
- Wersja/commit kodu:
- Obraz i SHA-256 lub sposób instalacji:
- Model Pi i rewizja:
- Ekran / karta USB / zestaw BT:
- Zasilanie:
- Wersje STL:
- OS / kernel:

| Próba | Oczekiwany wynik | Wynik / obserwacja |
| --- | --- | --- |
| Oględziny i mechanika | Brak zwarć/uszkodzeń, przyciski nie zakleszczają się, dostęp do złączy | |
| Pierwszy rozruch | System startuje, konfiguracja kończy się czytelnym statusem | |
| Własna tożsamość | Własne hasło, hostname i nowe klucze; brak kont/danych autora | |
| Rozmiar partycji | Rootfs wykorzystuje docelową kartę zgodnie z planem | |
| Ekran i cztery przyciski | Poprawna orientacja, każde sterowanie odpowiada opisowi | |
| Display | Kolory, jasność i timeout działają oraz pozostają po restarcie | |
| LAN / Wi-Fi | Połączenie, adres i autoconnect po restarcie | |
| Nowa sieć Wi-Fi | Skan, wpisanie hasła, wybór profilu i profil domyślny | |
| WWW przez IP / nazwę | Dostęp w LAN, poprawne logowanie i odmowa błędnego hasła | |
| User / reflektor | Własne dane zapisują się; status odpowiada stanowi połączenia | |
| Wybór TG | Wybrana grupa odpowiada stanowi urządzenia i panelu | |
| Monitorowanie / RX | Odbiór, callsign i wskaźnik dla faktycznej transmisji | |
| USB audio | Mikrofon i odsłuch na zamierzonym urządzeniu, regulacja głośności | |
| Bluetooth audio | Parowanie, połączenie, właściwy profil i działanie po restarcie | |
| PTT — kontrola bez nadawania | Wejście stabilne, puszczenie zwalnia PTT, start z wciśniętym przyciskiem nie uzbraja nadawania | |
| PTT — uzgodniony test głosu | Kontrolowana próba z odbiorcą, wyraźny początek i koniec; bez pozostania TX | |
| Odsłuch WWW | USB/BT nadal grają lokalnie, osobna głośność przeglądarki, Stop działa | |
| Zmiana strony / wylogowanie | Strumień odsłuchu kończy się | |
| Utrata i powrót sieci | Czytelny status oraz udokumentowane zachowanie ponownego łączenia | |
| Dłuższa praca | Zapis czasu obserwacji, ewentualnych rozłączeń i ich przyczyn | |
| Ponowny start | Konfiguracja pozostaje, usługi/audio startują w poprawnej kolejności | |
| Własny backup i odtworzenie | Udokumentowana kopia i odtworzenie na osobnej karcie | |

Test PTT bez nadawania musi być zorganizowany tak, aby drugi proces nie uruchamiał równolegle toru TX. Szczegóły trybu `--dry-run` i usługi sprawdź przed testem. Nie uruchamiaj drugiego procesu zajmującego GPIO26 równocześnie z normalną usługą przycisku.

## Podsumowanie egzemplarza

- Zaliczone:
- Błędy i sposób odtworzenia:
- Niesprawdzone:
- Czy druga osoba odtworzyła urządzenie bez prywatnej pomocy autora:

## Panel Audio diagnostics

Według [instrukcji](../build/AUDIO-TESTS.md) sprawdź na USB i BT: słyszalny ton 2 s, miernik reagujący na mowę przez 8 s, Stop, automatyczne zakończenie, opuszczenie strony, blokadę podczas RX/PTT, wyciszony/brakujący sprzęt i zmianę routingu. Potwierdź, że lokalne audio SvxLink działa po teście i nie została zmieniona głośność. Nie używaj rzeczywistej transmisji jako automatycznego testu.

## Dopasowanie wejścia Bluetooth — poprawka 17 września 2026

PipeWire może nazwać wyjście `bluez_output.AA_BB_CC_DD_EE_FF.1`, a wejście `bluez_input.AA:BB:CC:DD:EE:FF`. Poprzedni wybór transportu oczekiwał podkreśleń i dodatkowego sufiksu także dla wejścia. Teraz dopasowuje znormalizowany adres urządzenia. Trzy testy regresji obejmują obie postacie BT i USB: `python3 software/tests/test_bt_pair.py`. Po zmianie sprawdź zarówno domyślne wejście, jak i źródło istniejącego strumienia SvxLink.

## Profile reflektorów

Według [instrukcji](../build/PROFILES.md) sprawdź tworzenie/edycję/usuwanie w obu interfejsach, maskowanie hasła, konflikt rewizji przy równoległej edycji, aktywację poprawnego konta, odtworzenie po błędnym koncie, blokadę PTT/RX oraz domyślny profil po restarcie. Potwierdź brak danych SQLink w Fali, zachowanie USB/BT i Wi-Fi oraz nazwę aktywnego profilu na ekranie. Pełny test Fali wymaga gotowego serwera i osobnego konta.

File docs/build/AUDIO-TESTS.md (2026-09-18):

# Testowanie audio w panelu WWW

Otwórz `https://pitalk-pro.local:8443/#audio` i zaloguj się kontem systemowym `sqlink`.

1. Wybierz USB audio card lub Bluetooth headset. Dla Bluetooth najpierw połącz urządzenie i wybierz profil zapewniający mikrofon.
2. W razie potrzeby ustaw osobno Output device / Input microphone w Advanced routing i zatwierdź odpowiednim Apply. Wybrana pozycja listy nie zmienia routingu do chwili zatwierdzenia.
3. Ustaw wygodną głośność. W Audio diagnostics wybierz **Test speaker · 2 s**. Ton 660 Hz zabrzmi na fizycznym urządzeniu, a nie w przeglądarce. Test nie zmienia głośności urządzenia; własny strumień ma ograniczony poziom. Komunikat zakończenia potwierdza odtworzenie strumienia, słyszalność potwierdza użytkownik.
4. Wybierz **Test microphone · 8 s** i mów do mikrofonu bez naciskania PTT. Pasek pokazuje RMS od −60 do 0 dBFS. Wartość −60 obejmuje również sygnały poniżej tego progu. Bardzo niski poziom podczas ciszy jest normalny. Wynik „Signal detected” potwierdza obecność sygnału, nie zrozumiałość mowy ani odbiór przez reflektor.
5. **Stop test** przerywa test. Opuszczenie Audio lub wylogowanie również zleca zatrzymanie. Niezależny limit po stronie urządzenia kończy test także przy utracie połączenia z przeglądarką.

Test nie włącza PTT, nie zapisuje mikrofonu i nie przesyła próbek mikrofonu do przeglądarki. Zwracane są jedynie wartości poziomu. USB i Bluetooth korzystają z tego samego mechanizmu PipeWire/PulseAudio. Wyjście i wejście nie są przejmowane na wyłączność; SvxLink zachowuje swój tor audio.

Test jest blokowany przy RX/PTT lub niedostępnym stanie radia. Pojawienie się aktywności podczas testu powoduje jego przerwanie. Jest to kontrola programowa, nie sprzętowa blokada PTT — nie naciskaj PTT w celu testowania tonu. Zmiana domyślnego routingu kończy test przy kolejnym sprawdzeniu. W danej chwili może działać tylko jeden test, a zatrzymać go przez API może sesja, która go uruchomiła.

## Zależności i wdrażanie

Moduł `/opt/sqlink-web/audio_test.py`, `paplay`, `parec`, `pactl` i dostęp usługi panelu do socketu PulseAudio. Korzysta z istniejącego bind mount i `PULSE_SERVER`; nie wymaga nowych uprawnień. API GET/POST `/api/audio-test` wymaga sesji, POST także CSRF. Modyfikacja nie zmienia konfiguracji SvxLink ani zapisanych urządzeń.

## Weryfikacja 17 września 2026

- 9 testów logiki: poziom sygnału, blokada RX/PTT, walidacja urządzenia, wyciszenie, właściciel zadania, anulowanie, zmiana routingu, limit mikrofonu i brak próbek.
- 5 testów HTTP: brak sesji, CSRF, status, nieobsługiwana akcja i start/stop.
- Symulacja przeglądarki: wskaźnik, przyciski, Stop, opuszczenie widoku, szerokość telefonu i brak błędów JS.
- Prototyp USB: odczyt mikrofonu przez 8 sekund (niski poziom podczas sprawdzenia), proces odtwarzania tonu zakończony kodem 0; PTT pozostał nieaktywny. Test wykonano z konta i w przestrzeni montowań usługi panelu.
- Do potwierdzenia przez użytkownika: słyszalność tonu, reakcja na mowę i rzeczywisty test zestawu Bluetooth. Nie przełączano używanego sprzętu na BT podczas wdrożenia.

Lokalnie: `python3 software/tests/test_audio_test.py` oraz `python3 software/tests/test_http.py`. Test HTTP otwiera tymczasowy port localhost i korzysta z atrap, nie steruje radiem. Obraz alpha-1 nie został przebudowany i nie zawiera tej aktualizacji.

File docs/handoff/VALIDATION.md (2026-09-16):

# Kontrola pakietu przekazania

16 września 2026.

- Eksport 46 plików kodu/usług z jawnej listy urządzenia; sumy kopii zgodne z manifestem eksportu.
- Składnia wszystkich 28 plików Python poprawna; kontrola bez uruchamiania modułów sprzętowych.
- Składnia plików JavaScript i skryptów shell poprawna.
- Symulacja konfiguracji nowego obrazu: PASS, pliki tymczasowe i zastąpione operacje systemowe.
- Sprawdzono wzorce kluczy prywatnych i przypisań sekretów; w kodzie nie znaleziono wskazanych wzorców. To kontrola ograniczona, nie pełny audyt bezpieczeństwa.
- LOCAL-ACCESS.md jest wykluczony przez Git i ma prawa 600.
- Zachowano istniejące STL, filmy i inne materiały; zmieniono README, dodając informacje o kodzie.
- Nie wdrażano zmian na urządzeniu i nie wykonano commit/push.

Automatyczna kontrola bezpieczeństwa odrzuciła pierwszą próbę eksportu ze względu na ryzyko pobrania tokenu PulseAudio. Zastosowano węższą jawną listę kodu i usług, bez plików domowych, cookies, profili i kluczy. Taki eksport zakończył się poprawnie. Konfigurację WirePlumber odtworzono jako przykład z zapisanej wcześniej poprawki.

Ograniczenia: testy statyczne nie potwierdzają działania na nowej instalacji. Obraz alpha nie przeszedł fizycznego rozruchu. Eksport ma przykładowy filtr LAN i nie jest przeznaczony do zbiorczego nadpisania istniejącego urządzenia.

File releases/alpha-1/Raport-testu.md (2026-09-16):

# PiTalk Pro alpha-1 — weryfikacja obrazu

Data przygotowania: 16 września 2026.

## Sprawdzone

- Obraz dysku 6 GiB, tablica MBR, partycja FAT32 `bootfs` 512 MiB i partycja ext4 `rootfs`.
- Kontrola FAT32 i ext4 zakończona bez błędów.
- Inspekcja obu partycji zamontowanych tylko do odczytu: pliki startowe Raspberry Pi 3, nakładka PiTFT, zgodność PARTUUID z konfiguracją rozruchu i montowania.
- Obecność i uprawnienia programu pierwszego uruchomienia, włączenie jego usługi, składnia głównych programów Python.
- Symulacja pierwszej konfiguracji: ustawienie danych, zapis chronionego profilu Wi-Fi, usunięcie pliku konfiguracyjnego z hasłami oraz brak powtarzania konfiguracji po inicjalizacji.
- Puste konto tożsamości urządzenia (`machine-id`), zablokowane hasła kont przed konfiguracją, brak starych kluczy SSH/HTTPS i profili Wi-Fi.
- Skan plików porównujący zawartość z prywatnymi danymi urządzenia źródłowego. Jedyny wskazany plik był opcjonalnym przykładem dokumentacji cloud-init; został usunięty z obrazu. Raport nie zawiera sekretów.
- Obraz powstał na nowym systemie plików, a nie przez kopiowanie wolnych bloków oryginalnej karty.

## Ograniczenia

Nie zapisano karty microSD i nie uruchomiono fizycznego urządzenia z tego obrazu. Rozruch, powiększanie partycji, pierwsza konfiguracja, kolejność startu usług i działanie sprzętu wymagają testu na zapasowej karcie. Kopię plików pobrano z działającego urządzenia; nie jest to migawka zatrzymanego systemu.

To prywatna wersja testowa, a nie zatwierdzone wydanie do publicznej dystrybucji. Ustawienia działającego urządzenia źródłowego nie zostały zastąpione ustawieniami fabrycznymi obrazu.

## Końcowa kontrola kopii na Macu

- Suma SHA-256 pierwotnego transferu była zgodna z plikiem na Raspberry Pi. Następnie lokalny obraz zaktualizowano o domyślny hostname; aktualna suma znajduje się w `SHA256SUMS`.
- Pełna kontrola gzip: bez błędów.
- Tablica MBR odczytana z lokalnego archiwum: zgodna z planowanym układem partycji.
- Rozmiar skompresowany: 917741140 bajtów (875.2 MiB).
- Rozmiar po rozpakowaniu: 6 442 450 944 bajty (6 GiB).

## Aktualizacja domyślnej nazwy

Ustawiono `hostname` na `pitalk-pro` w `pitalk-setup.json` wewnątrz obrazu i w dołączonym szablonie. Porównanie wszystkich bajtów z poprzednim obrazem potwierdziło zmiany wyłącznie w zawartości tego pliku i jego polu rozmiaru w katalogu FAT32. Partycja root pozostała identyczna. Kontrola FAT32 po aktualizacji nie wykazała błędów. Nazwa zostanie zastosowana przy pierwszym poprawnym skonfigurowaniu nowej instalacji.

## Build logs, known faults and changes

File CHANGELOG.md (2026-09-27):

# Historia zmian PiTalk Pro

Historia opisuje zmiany funkcjonalne i zakres ich sprawdzenia. Szczegóły kodu znajdują się w commitach, a gotowość do odtworzenia urządzenia w [READINESS](docs/project/READINESS.md).

## 2026-09-27 — System Info na urządzeniu 0.1.5

- Trzy strony informacji w menu PiTFT: wersja i system, sprzęt i temperatura, bieżące oraz historyczne błędy zasilania.
- Odczyty w tle, przełączanie enkoderem i odświeżanie kliknięciem. Sprawdzono podglądy wszystkich stron.

## 2026-09-27 — System Info 0.1.4

- Nowa zakładka WWW z informacjami o urządzeniu, wersji aplikacji, systemie i temperaturze.
- Bieżące błędy zasilania oddzielono od flag historycznych; brak danych nie oznacza poprawnego zasilania.
- Sprawdzono składnię JS/Python, 11 testów API i 7 testów aktualizatora. Fizyczny test panelu po aktualizacji pozostaje do potwierdzenia.

## 2026-09-27 — Wydanie 0.1.3 i migracja WWW

- Rozszerzono aktualizator prototypu o WWW, zachowując prywatną konfigurację LAN poza plikami aplikacji.
- Wydanie 0.1.3 zawiera panel System Update. Kontrola działania obejmuje ekran i odpowiedź HTTPS; rollback obejmuje cały zestaw.
- Aktualizacja restartuje również WWW i wymaga ponownego zalogowania. Test fizycznej instalacji 0.1.3 pozostaje do potwierdzenia.

## 2026-09-27 — Panel WWW: obsługa aktualizacji (przygotowana)

- Dodano System Update z wersjami, sprawdzaniem, potwierdzeniem instalacji i odświeżaniem statusu.
- Nowe API korzysta z sesji, CSRF i ograniczonego helpera urządzenia. Wdrożenie WWW wymaga rozszerzenia obecnego aktualizatora; kanał stable pozostaje 0.1.2.

## 2026-09-27 — System Update 0.1.2

- Dopasowano nagłówek, separatory i zaznaczenie do pozostałych menu. Usunięto dodatkową etykietę wersji testowej; wersja instalacji pozostaje w Current.
- Potwierdzenie instalacji i komunikaty mają oddzielne obszary. Długie teksty są ograniczane według szerokości w pikselach.
- Sprawdzono rendery 240×320 okna głównego, potwierdzenia i długiego błędu; fizyczny test instalacji przez menu pozostaje do wykonania.

## 2026-09-27 — Wydanie testowe 0.1.1

- Dodano widoczny napis `Update UI v0.1.1` w menu aktualizacji, aby potwierdzić załadowanie nowego kodu po instalacji z urządzenia.
- Pozostałe trzy pliki aplikacji bez zmian. Wydanie przeznaczone do pierwszego fizycznego testu aktualizatora; wynik testu nie jest jeszcze potwierdzony.

## 2026-09-27 — Aktualizacje bez blokady napięcia

- Na wyraźne życzenie właściciela usunięto sprawdzanie undervoltage z blokady instalacji. Zachowano kontrolę RX/PTT, wolnego miejsca, kopię i rollback. Zaktualizowano usługę na terminalu.

## 2026-09-27 — Enkoder i aktualizator aplikacji 0.1.0

- Zapisano działającą obsługę EC11 i głośności z terminala.
- Dodano System Update: oznaczone wersje GitHub, kontrola sum, kopia i automatyczne wycofanie.
- Wersja 1 obejmuje cztery pliki ekranu/enkodera; blokuje instalację podczas RX/PTT i przy niskim napięciu.
- Testy transakcji i wycofania na plikach tymczasowych; fizyczny cykl aktualizacji wymaga jeszcze potwierdzenia. [Instrukcja](docs/build/UPDATES.md).

## 2026-09-27 — Kompletny zestaw STL V39/V42

- Dodano katalog i ZIP: korpus V39, front V42, nakładka V11 (druk 4 szt.), podstawa anteny i antena 70 mm. Nazwy plików po angielsku.
- Sprawdzono zgodność kopii z plikami źródłowymi i integralność ZIP. Gałka enkodera pozostaje do zaprojektowania.

## 2026-09-26 — Korpus V39 i front V42 pod EC11

- Dodano STL i edytowalne STEP; zachowano wcześniejsze części.
- Wydłużono górę o 8 mm pod jeden EC11 i antenę, zamknięto slot microSD i ujednolicono zewnętrzne ścianki.
- Dodano tylne otwory Ø3.4 z gniazdami Ø6.4 / 2.2; wyśrodkowano 40 otworów dna względem śrub.
- Front V42 ma dwa rzędy po trzy otwory nad ekranem.
- Sprawdzono CAD i import STEP; autor potwierdził przymiarkę próbnego górnego odcinka. Pełny montaż i integracja enkodera pozostają do sprawdzenia. [Szczegóły](docs/build/MECHANICAL-EC11.md).

## 2026-09-22 — Czytelniejszy nagłówek profilu

- Po ocenie układu stopki przeniesiono profil pod znak wywoławczy, ponad górną linię.
- Nazwa jest wyśrodkowana, ma większą czcionkę i korzysta z szerokości nagłówka; długie nazwy zachowują wielokropek.
- Stopka zawiera ponownie ikonę menu i zegar. Sprawdzono podgląd krótkiej i długiej nazwy; wdrożono po kopii skryptu.

## 2026-09-22 — Nazwa profilu obok zegara

- Przeniesiono aktywny profil z górnej części ekranu na dół, między ikonę menu a godzinę.
- Dostępna szerokość uwzględnia zegar; długie nazwy kończą się wielokropkiem.
- Sprawdzono renderowanie krótkiej i długiej nazwy. Przed wdrożeniem zapisano kopię skryptu; restart obejmuje tylko ekran.

## 2026-09-22 — Profile reflektorów

### Funkcje

- Wspólne profile połączenia w menu PiTFT i panelu WWW: dodawanie, edycja, aktywacja, profil domyślny na rozruch oraz usuwanie.
- Import istniejącego konta do SQLink i utworzenie osobnego profilu Fala dla `fala.zasieg.pl`, bez kopiowania hasła SQLink.
- Zapis ustawień oddzielony od aktywacji; każdy profil przechowuje własny serwer, port, konto i TG.
- Blokada przełączenia podczas PTT/RX, ochrona przed równoległą edycją oraz przywracanie konfiguracji przy nieudanej aktywacji.
- Nazwa aktywnego profilu na ekranie głównym i w panelu; dane stacji SQLink nie są pobierane dla profilu bez wybranego katalogu SQLink.

### Sprawdzenie i ograniczenia

- 12 testów backendu, 3 testy menu/API oraz 5 testów ochrony HTTP zakończonych powodzeniem. Symulacja WWW obejmuje formularze, pomijanie pustego hasła i układ mobilny.
- Na prototypie sprawdzono import, zapis/usunięcie profilu testowego, odrzucenie niepełnej konfiguracji i renderowanie menu. Końcowy odczyt potwierdził aktywne połączenie Fali.
- Przed wdrożeniem wykonano prywatny backup aplikacji i konfiguracji na urządzeniu i Macu; sumy kopii były zgodne. Backup nie jest częścią repozytorium.
- Audio/TG Fali, powrót do SQLink i rozruch z innym profilem wymagają dalszych testów. Obraz alpha-1 nie został przebudowany.

[Instrukcja i odtwarzanie](docs/build/PROFILES.md) · [Sumy plików aktualizacji](software/profiles-release.json)

## Wcześniejsze prace

Przekazanie projektu, testy audio i poprawka dopasowania mikrofonu Bluetooth są opisane w [dokumentacji rozwoju](docs/handoff/START-HERE.md), [testach audio](docs/build/AUDIO-TESTS.md) i dotychczasowej historii Git. Nie przypisujemy im nowych numerów wydania firmware.

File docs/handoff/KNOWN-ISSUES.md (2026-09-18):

# Ograniczenia i nierozstrzygnięte sprawy

## Potwierdzone podczas wcześniejszych prac

- Wi-Fi przestało działać, gdy NetworkManager nie miał zapisanego profilu. Po utworzeniu profilu połączenie działało, autoconnect był włączony, interfejs wlan0 i DHCP poprawne. Przyczyny wcześniejszego zniknięcia profilu nie ustalono — nie przedstawiaj domysłu jako faktu.
- Surowy przycisk PTT dawał serię krótkich zboczy; debounce 30 ms dał czytelne pary wciśnięcie/puszczenie.
- Powtarzany komunikat Bluetooth „connected to device” analizowano i dodano konfigurację WirePlumber dla pracy bez sesji graficznej. Właściciel potwierdził poprawę. Zachowaj ją przy odtwarzaniu systemu.
- Odsłuch WWW zgłaszał brak wyjścia audio z powodu izolacji `/run/user` przez systemd. Dodano jawny bind socketu i `PULSE_SERVER`.
- Występowały rozłączenia reflektora z timeoutem heartbeat przy działającej sieci. Zaobserwowano automatyczne ponowne łączenie. Nie wykazano definitywnego usunięcia przyczyny po stronie całej ścieżki sieci/serwera. Potencjalny drugi klient używający tych samych danych rozważano, ale nie należy zakładać, że wyjaśnia każdy przypadek OFFLINE.
- Rotacja logu SvxLink wymagała poprawnych właścicieli oraz HUP; dołączono aktualny plik logrotate.

## Ograniczenia kodu/prototypu

- Prywatny filtr LAN/Host jest wpisany w kod panelu. W eksporcie zastąpiony przykładem. To istotny punkt przy wdrożeniu na innym routerze.
- UID/GID 1002 i gpio536 są zależnościami konkretnej instalacji.
- „Brightness” jest programowym przyciemnieniem renderowanego obrazu (LUT Pillow), a nie potwierdzonym sterowaniem mocą podświetlenia/PWM.
- Wygląd UI, przepływy menu i strumienie audio nie mają kompletnego automatycznego pokrycia testami. Składnia nie zastępuje testu na sprzęcie.
- Monitorowanie wielu TG nie jest mikserem równoczesnych rozmów. Trzeba odróżniać skonfigurowaną listę, aktualnie wybraną TG i to, co jest faktycznie odbierane.
- Pasek audio pokazuje poziom lokalnych próbek. Nie jest skalibrowanym miernikiem RF ani potwierdzeniem odbioru przez innych.
- BT zależy od dostępności urządzenia, profilu i domyślnego sink/source; sprawdź rzeczywisty sprzęt po zmianie routingu.
- Certyfikat panelu jest samopodpisany. `.local` wymaga mDNS; gdy nie działa, używa się adresu IP. Sam hostname nie zapewnia dostępu między odseparowanymi sieciami.
- Pole „config stacji” w popupie pokazuje dane udostępnione przez API reflektora, nie daje uprawnień do zmiany obcego urządzenia.

## Obraz alpha i publikacja

Obraz 6 GiB ma poprawne systemy plików i przeszedł kontrole statyczne, ale nie był uruchomiony z nowej karty. Wymaga testów: rozruch, pierwsza konfiguracja, powiększenie partycji, kolejność usług, ekran, PTT, USB, BT, Wi-Fi, WWW i audio. Zbudowano go z plików pobranych z pracującego Pi, nie z zatrzymanej migawki.

Pierwsza konfiguracja używa pliku na partycji FAT. Po użyciu jest nadpisywany i usuwany; nie traktuj tego jako gwarantowanego fizycznego wymazania pamięci flash. Nigdy nie publikuj obrazu po skonfigurowaniu go własnymi hasłami.

Przed publicznym wydaniem pozostają: instalator/powtarzalny build, pełne testy sprzętowe, przegląd licencji i źródeł zależności, instrukcja recovery oraz przegląd bezpieczeństwa panelu/helperów. Nie ustalono gotowej licencji całego oprogramowania w tej sesji; nie wymyślaj jej.

## Sensowna kolejność dalszych prac

1. Test alpha na zapasowej karcie, bez nadpisania działającej instalacji.
2. Usunięcie stałych IP/UID/mapowania GPIO przez konfigurację i wykrywanie.
3. Uporządkowany instalator i testy najważniejszych stanów PTT/TG/audio.
4. Diagnostyka heartbeat oparta na dłuższej obserwacji, jeżeli problem powróci.
5. Przygotowanie wersji do dystrybucji po testach i przeglądzie materiałów.

## Dopasowanie wejścia Bluetooth — poprawka 17 września 2026

PipeWire może nazwać wyjście `bluez_output.AA_BB_CC_DD_EE_FF.1`, a wejście `bluez_input.AA:BB:CC:DD:EE:FF`. Poprzedni wybór transportu oczekiwał podkreśleń i dodatkowego sufiksu także dla wejścia. Teraz dopasowuje znormalizowany adres urządzenia. Trzy testy regresji obejmują obie postacie BT i USB: `python3 software/tests/test_bt_pair.py`. Po zmianie sprawdź zarówno domyślne wejście, jak i źródło istniejącego strumienia SvxLink.

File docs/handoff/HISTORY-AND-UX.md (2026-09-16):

# Historia decyzji i preferencje

To chronologia funkcjonalna z dostępnego kontekstu; aktualny kod ma pierwszeństwo przed wcześniejszymi prośbami o wygląd.

## Urządzenie

Na początku pomylono płytki. Model potwierdzony z systemu to Raspberry Pi 3 Model B Rev 1.2. Brak Wi-Fi rozwiązano przez utworzenie profilu NetworkManager. Następnie uruchomiono trwały PTT, osobną usługę przycisku i bezpieczny stan GPIO24.

## Menu PiTFT

- Właściciel wybrał wpisywanie danych przyciskami przez klawiaturę ekranową.
- Wi-Fi: skan, dodawanie sieci, wybór zapisanej, profil domyślny/autoconnect.
- Menu ujednolicono kolorystycznie. Tytuły zmniejszono, dopasowano położenie i linie oddzielające zawartość.
- Na ekranie głównym usunięto datę na rzecz oznaczenia MENU.
- Fizyczne przyciski są po lewej: ikona BACK u góry po lewej, pozostałe oznaczenia u dołu. Dodatkowe przesunięcie ikon o 4 px zostało później cofnięte.
- Na ekranie głównym BACK i UP miały być nieaktywne, DOWN prowadzić do wyboru Talk Groups. Faktyczne mapowanie sprawdzaj w końcowej pętli `sqlink-screen.py`.
- Powrót po bezczynności początkowo 10 s, potem 30 s; obecnie wartość jest ustawieniem Display. Nie nadpisuj jej globalną stałą.
- Display: Brightness w procentach, schemat kolorów i idle timeout; zapis między restartami.
- Restart: osobne menu kontroli restartu.
- Bluetooth: skanowanie, parowanie i wybór urządzenia, połączenie/rozłączenie oraz opcje audio; stan przez helper.
- Audio: USB lub Bluetooth oraz Volume. Zmianę głośności poprawiono tak, aby każde UP/DOWN nie wywoływało blokującego ekranu „Reading audio”.
- User: login/callsign i hasło reflektora, grupa domyślna, monitorowane grupy oraz zapis z ponownym połączeniem.

## Ekran główny

ONLINE jest zielone, OFFLINE czerwone. Status pracy MONITOR/RX/TX jest odrębny od połączenia. Podczas RX pokazuje się callsign nadawcy, większy i w niebieskim kolorze, wyśrodkowany między nazwą grupy a statusem. Numer TG zmniejszono; nazwa grupy jest bezpośrednio pod nim. Pasek poziomu audio odświeża się szybciej podczas odbioru, bez kosztownego pełnego odczytu stanu na każdej klatce.

## Panel WWW

Najpierw rozważano brak hasła, ale końcowa decyzja właściciela to logowanie systemowym kontem `sqlink` i jego hasłem. Zachowaj uwierzytelnianie. Panel otrzymał aktywność TG, listy stacji, popup po callsign, zarządzanie urządzeniem i odsłuch.

Odsłuch WWW miał zachować dźwięk na fizycznym urządzeniu, działać dla USB i Bluetooth oraz mieć niezależną głośność przeglądarki. Nie jest funkcją nadawania z mikrofonu przeglądarki.

## Prezentacje i inne rozmowy

Przygotowywano filmy panelu i fizycznego ekranu z polskimi napisami oraz syntetycznym lektorem. Pełny przegląd urządzenia obejmował 67 kroków. Tymczasowy mechanizm sterowania ekranem na potrzeby filmu został usunięty, a zwykła usługa przywrócona.

Rozmawiano też o własnym reflektorze, EuroLink/EchoLink i konferencjach EchoLink. W dostępnej historii nie ma potwierdzenia wdrożenia własnego serwera ani modułu EchoLink w tym projekcie. Nie przedstawiaj tych rozmów jako działających funkcji ani aktualnych ustaleń formalnych.

## Preferencje współpracy

Właściciel woli, aby asystent wykonywał zlecone zmiany sam, korzystając z dostępnego terminala/SSH. Nie chce ciągłego ponownego pytania o już uzgodnione czynności. Jednocześnie ważne są kopie, zachowanie danych logowania, brak ujawniania sekretów i jasna informacja, co sprawdzono. Opisy dla użytkownika po polsku, teksty produktu po angielsku.

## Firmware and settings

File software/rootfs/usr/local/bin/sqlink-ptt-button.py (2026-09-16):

#!/usr/bin/python3
"""Hold-to-talk GPIO26 input; GPIO24 output remains owned by SQLink."""
import argparse
import signal
import socket
import sys
import os
import time


class Button:
    def __init__(self):
        self.raw = None
        self.since = 0.0
        self.stable = None
        self.armed = False
        self.active = False

    def update(self, level, now):
        if level not in (0, 1):
            raise RuntimeError("Invalid GPIO input")
        if level != self.raw:
            self.raw, self.since = level, now
        if now - self.since < 0.030 or level == self.stable:
            return None
        self.stable = level
        if level == 1:
            self.armed = True
        active = self.armed and level == 0
        if active == self.active:
            return None
        self.active = active
        return active


def notify(message):
    address = os.environ.get("NOTIFY_SOCKET")
    if not address:
        return
    if address.startswith("@"):
        address = "\0" + address[1:]
    with socket.socket(socket.AF_UNIX, socket.SOCK_DGRAM) as sock:
        sock.sendto(message.encode(), address)


def main():
    parser = argparse.ArgumentParser()
    parser.add_argument("--dry-run", action="store_true")
    parser.add_argument("--release", action="store_true")
    args = parser.parse_args()
    sys.path.insert(0, "/usr/lib")
    from sqlink import gpio
    if args.release:
        gpio.ptt_off()
        return
    import lgpio
    running = True

    def stop(signum, frame):
        nonlocal running
        running = False

    signal.signal(signal.SIGTERM, stop)
    signal.signal(signal.SIGINT, stop)
    handle = None
    try:
        if not args.dry_run:
            gpio.ptt_off()
        handle = lgpio.gpiochip_open(0)
        lgpio.gpio_claim_input(handle, 26, lgpio.SET_PULL_UP)
        button = Button()
        print("GPIO26 ready; debounce=30ms; release before first press; dry_run="
              + str(args.dry_run), flush=True)
        notify("READY=1")
        last_watchdog = 0.0
        while running:
            now = time.monotonic()
            change = button.update(lgpio.gpio_read(handle, 26), now)
            if change is not None:
                if not args.dry_run:
                    (gpio.ptt_on if change else gpio.ptt_off)()
                print("PTT ON" if change else "PTT OFF", flush=True)
            if now - last_watchdog >= 0.5:
                notify("WATCHDOG=1")
                last_watchdog = now
            time.sleep(0.005)
    finally:
        try:
            if not args.dry_run:
                gpio.ptt_off()
            print("PTT monitor stopped", flush=True)
        finally:
            if handle is not None:
                lgpio.gpiochip_close(handle)


if __name__ == "__main__":
    main()

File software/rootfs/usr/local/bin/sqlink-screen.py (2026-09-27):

#!/usr/bin/env python3

import os
import re
import time
import subprocess
import json
import urllib.request
from datetime import datetime

import lgpio
from PIL import Image, ImageDraw, ImageFont
from sqlink import theme
from sqlink.theme import MenuDraw, footer_icons
from sqlink.display import Settings, DisplayMenu
display_settings = Settings()
display_menu = DisplayMenu(display_settings)
from sqlink.update_ui import UpdateMenu, SystemInfoMenu
update_menu = UpdateMenu()
info_menu = SystemInfoMenu()
from sqlink.restart_ui import RestartMenu
restart_menu = RestartMenu()
from sqlink.bluetooth_ui import BluetoothMenu
bluetooth_menu = BluetoothMenu()
from sqlink.audio_ui import AudioMenu
audio_menu = AudioMenu()
from sqlink import profile_state
from sqlink.user_ui import UserMenu
user_menu = UserMenu()

import sys
sys.path.insert(0, "/usr/lib")

from sqlink.controller import SQLinkController

controller = SQLinkController()

from sqlink.wifi_ui import WiFiMenu
wifi_menu = WiFiMenu()

FB = "/dev/fb0"
WIDTH = 240
HEIGHT = 320

SVXCONF = "/etc/svxlink/svxlink.conf"
SVXLOG = "/var/log/svxlink"

BUTTONS = {
    17: "BACK",
    22: "UP",
    23: "DOWN",
    27: "ENTER",
}

MAIN_MENU = [
    "SQLink",
    "Audio",
    "User",
    "Bluetooth",
    "WiFi",
    "Display",
    "System Update",
    "System Info",
    "Restart",
]

SQLINK_MENU = [
    "Network",
    "Active TG",
    "Last QSO",
    "Stations",
    "Node Info",
    "Talk Groups",
]

FALLBACK_TG_LIST = [
    ("260", "Polska"),
    ("2600", "Ogólnopolska"),
    ("26077", "SQLink"),
    ("260073", "Akcje Dyplomowe"),
    ("999", "Echo / Test"),
    ("27252", "Ireland"),
    ("3109312", "Chicago"),
]

TG_NAMES = {
    "260": "Polska",
    "2600": "Ogólnopolska",
    "26077": "SQLink",
    "260073": "Akcje Dyplomowe",
    "999": "Echo / Test",
    "27252": "Ireland",
    "3109312": "Chicago",
}

TG_LIST = list(FALLBACK_TG_LIST)

TG_API_URL = "https://sqlink.pl/tg_names.json"
TG_REFRESH_INTERVAL = 600
last_tg_refresh = 0.0


def font(size, bold=False):
    path = (
        "/usr/share/fonts/truetype/dejavu/DejaVuSans-Bold.ttf"
        if bold
        else "/usr/share/fonts/truetype/dejavu/DejaVuSans.ttf"
    )
    try:
        return ImageFont.truetype(path, size)
    except Exception:
        return ImageFont.load_default()



FONT_TITLE = font(27, True)
FONT_CALL = font(25, True)
FONT_TG = font(23, True)
FONT_MED = font(18, True)
FONT_SMALL = font(15)
FONT_TINY = font(12)
FONT_MENU = font(20, True)
FONT_MENU_SMALL = font(17)


def read_callsign():
    try:
        section = None
        with open(SVXCONF, "r", errors="ignore") as f:
            for raw in f:
                line = raw.strip()

                if line.startswith("[") and line.endswith("]"):
                    section = line
                    continue

                if (
                    section == "[SimplexLogic]"
                    and line.startswith("CALLSIGN=")
                ):
                    return line.split("=", 1)[1].strip().strip('"')
    except Exception:
        pass

    return "SQLink"



def read_recent_log():
    try:
        with open(SVXLOG, "rb") as f:
            f.seek(0, os.SEEK_END)
            size = f.tell()
            f.seek(max(0, size - 65536))
            return f.read().decode("utf-8", errors="ignore")
    except Exception:
        return ""



def get_active_tg(log):
    patterns = [
        r"Selecting TG #(\d+)",
        r"Talker start on TG #(\d+):",
    ]

    matches = []

    for pattern in patterns:
        for m in re.finditer(pattern, log):
            matches.append((m.start(), m.group(1)))

    if not matches:
        return "---"

    matches.sort(key=lambda x: x[0])
    return matches[-1][1]




def get_tg_name(tg):
    if not tg or tg == "---":
        return ""

    for item_tg, item_name in TG_LIST:
        if str(item_tg) == str(tg):
            return str(item_name)

    return ""



def reflector_connected(log):
    auth = log.rfind("Authentication OK")
    disc1 = log.rfind("Disconnected from")
    disc2 = log.rfind("Heartbeat timeout")

    return auth >= 0 and auth > max(disc1, disc2)



def wifi_info():
    try:
        result = subprocess.run(
            [
                "nmcli",
                "-t",
                "-f",
                "DEVICE,STATE,CONNECTION",
                "device",
            ],
            capture_output=True,
            text=True,
            timeout=2,
        )

        ssid = None

        for line in result.stdout.splitlines():
            parts = line.split(":", 2)

            if len(parts) == 3:
                dev, state, connection = parts

                if dev == "wlan0" and state == "connected":
                    ssid = connection
                    break

        ip = subprocess.run(
            ["hostname", "-I"],
            capture_output=True,
            text=True,
            timeout=2,
        ).stdout.strip().split()

        ipaddr = ip[0] if ip else "---"

        return ssid or "WiFi OFF", ipaddr

    except Exception:
        return "WiFi ?", "---"




def extract_tgs(obj):
    found = set()

    def add_tg(value):
        if value is None:
            return

        text = str(value).strip()

        if text.isdigit():
            num = int(text)

            # Ignore TG0 / empty state.
            if num > 0:
                found.add(str(num))

    def walk(x, parent_key=""):

        if isinstance(x, dict):

            for key, value in x.items():

                key_l = str(key).lower()

                # Single TG-valued fields
                if key_l in (
                    "tg",
                    "talkgroup",
                    "talk_group",
                    "talkgroupid",
                    "talk_group_id",
                    "defaulttg",
                    "default_tg",
                    "localtg",
                    "remotetg",
                ):
                    add_tg(value)

                # Lists of monitored TGs
                elif key_l in (
                    "monitoredtgs",
                    "monitored_tgs",
                    "talkgroups",
                    "talk_groups",
                ):
                    if isinstance(value, list):
                        for item in value:
                            add_tg(item)

                walk(value, key_l)

        elif isinstance(x, list):

            for item in x:
                walk(item, parent_key)

        elif isinstance(x, str):

            # Also catch human-readable TG references
            for m in re.finditer(
                r'(?i)(?:TG|talkgroup)[^0-9]{0,6}([0-9]{2,8})',
                x
            ):
                add_tg(m.group(1))

    walk(obj)

    return found
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

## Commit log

2026-09-16 initial version
    [01_Body_V32.stl, 02_Flat_Front_Panel_V38.stl, 03_Button_Cap_V11_Print_4.stl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]
2026-09-16 przejecie od chatgpt
    [parts.csv]
2026-09-22 fix(display): przenies aktywny profil obok zegara
    Usun nazwe profilu z gory ekranu. Umiesc ja miedzy ikona menu a godzina i skroc wielokropkiem wedlug dostepnej szerokosci. Sprawdzono renderowanie krotkiej i dlugiej nazwy; wdrozono po kopii skryptu, restartujac tylko ekran.
    [sqlink-screen.py]
2026-09-22 fix(display): uporzadkuj naglowek aktywnego profilu
    Umiesc profil pod znakiem wywolawczym zamiast w ciasnej stopce. Wycentruj podpis, zwieksz czcionke i ogranicz tekst do szerokosci naglowka. Sprawdzono podglad krotkiej i dlugiej nazwy; wdrozono z backupem i restartem tylko ekranu.
    [sqlink-screen.py]
2026-09-26 Add V39 EC11 body and V42 two-row vent front with STEP files
    [01_Body_V39.step, 01_Body_V39.stl, 02_Front_Panel_V42.step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]
2026-09-27 Publish complete V39 V42 STL print bundle
    [01_Body_V39.stl, 02_Front_Panel_V42.stl, 03_Button_Cap_V11_Print_4.stl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]
2026-09-27 Add EC11 controls and on-device application updater
2026-09-27 Prepare 0.1.1 visible on-device update test
2026-09-27 Offer 0.1.1 through the device update channel
2026-09-27 Offer 0.1.2 menu layout fix to devices
2026-09-27 Offer 0.1.3 web panel release to devices
2026-09-27 Offer System Info 0.1.4 to devices
2026-09-27 Add three-page System Info to device menu in 0.1.5
2026-09-27 Offer device System Info 0.1.5
